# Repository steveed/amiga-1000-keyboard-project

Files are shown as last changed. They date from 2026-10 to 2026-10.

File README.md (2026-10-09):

# amiga-1000-keyboard-project
An open source replacement PCB for the Commodore Amiga 1000 keyboard.

Rendered top view of the board

Rendered angled view of the board

The switch plate, generated from the PCB (1.2 mm FR4, version 1):

Rendered switch plate

Renders are regenerated by GitHub Actions whenever the board or plate changes.

## Project Goals
1. Provide a drop-in replacement keyboard PCB for original Amiga 1000 machines.

## Controller
The board takes the original Amiga 1000 keyboard controller (a mask-ROM 6500/1). A 6570 from an
A500/A2000/A3000 keyboard also works if KCLK and KDAT are swapped: solder the cable's white and green
wires into each other's pads on J1. With the original controller: white = KCLK (PA0, pin 38),
green = KDAT (PA1, pin 37), red = +5V, black = GND.

## Building
Everything runs in Docker through `make` (KiCad 10 and a small Python image):

- `make print` - 1:1 print sheets in `build/print/` (one 11x17 sheet, or two Letter sheets to tape together).
  Print at 100% / Actual size and check the 100 mm bar.
- `make drc` - refill the pours and fail on any DRC error or schematic/board mismatch.
- `make bom` - regenerate `pcb/bom.csv` from the schematic's Part fields.
- `make fab` - gerbers and drill files, zipped in `build/fab/`.
- `make plate` - the switch plate (DXF and a gerber zip for FR4) in `build/plate/`, generated from the PCB.
- `make case` - the printable case (four STLs and a preview) in `build/case/`, from `case/a1000_case.scad`. See [case/README.md](case/README.md).
- `make rev2-sch`, `make rev2-pcb`, `make rev2-route`, `make rev2-drc` - the rev 2 board (ATmega32U4, surface mount, Cherry MX). See [pcb/rev_2/README.md](pcb/rev_2/README.md).
- `make render` - the README renders in `build/render/`.
- `make release` - all of the above, collected in `build/release/`.

Pushing a `v*` tag runs `make release` on GitHub and publishes the files as a GitHub release.

## Reference Material
- [docs/amiga-a1000-schematics-all.pdf](docs/amiga-a1000-schematics-all.pdf) - Amiga 1000 schematics

## Credits
Future revisions are expected to reuse parts of Henryk Richter's [A500KB](https://github.com/HenrykRichter/A500KB) mechanical keyboard. This project uses the same license so that work can be incorporated.

## License
The PCB, its design files and all support code are licensed under [Creative Commons Attribution-NonCommercial-ShareAlike 4.0 International (CC BY-NC-SA 4.0)](https://creativecommons.org/licenses/by-nc-sa/4.0/). See [LICENSE.txt](LICENSE.txt) for the full text.

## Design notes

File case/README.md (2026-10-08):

# Case

A printable case for the PCB and switch plate, shaped after the original Amiga 1000 keyboard.
Everything is generated from [`a1000_case.scad`](a1000_case.scad); `make case` writes the four
printable STLs and an assembly preview to `build/case/`.

Coordinates are the PCB's, as in [`docs/measurements.md`](../docs/measurements.md): x from the
PCB's left edge, y up from its front edge. z = 0 is the parting line between the two shells.

## Where the shape comes from

No original case was measured. The outside is taken from a 1:8 scale model of the keyboard (a 3MF,
"Keyboard PRINTABLE v8"; not kept in the repo). Its keycaps were fitted to
`docs/switch-positions.csv`: 66 single-width caps match at a scale of 7.99 with 0.27 mm RMS error,
so the model is accurate to well under a millimetre in plan. At full size:

- Case 405.7 x 157.9 x 23.6 mm, 25.85 mm on its feet. It overhangs the PCB by 8.0 mm at the left,
  8.45 at the right, 8.15 at the front and 4.8 behind the controller tab.
- Flat top, no wedge. The front and back edges are rounded (about r 5.9). The ends are square.
- A groove round the middle at the parting line (the model steps it; here it is one 1.6 x 1.2 mm groove).
- One stepped opening for the main block and the top row, and one for the keypad. Every keycap
  centre has at least 9.69 mm clear to the edge, so a full 19.05 mm cap envelope fits.
- The model's key wells have a floor at z = 0.8, read here as the plate top.
- A sloped label recess behind the keys (x 31.5-282.1, y 125.9-143.4), its floor rising from
  z 8.34 at the front to 10.27 at the back.
- A 15.5 mm badge recess at the rear right, 0.5 mm deep, where the original has the Amiga logo.
- A 0.3 mm label recess underneath, and four 19 mm square feet, 2.25 mm tall.

## From photos of an original case

Photos of an original top and bottom case (not kept in the repo), scaled from a steel rule in
the frame. Positions are good to a few millimetres.

- Overall length agrees with the model: about 406 mm.
- The bottom case has bosses at all four case-screw positions: the PCB's three 7.5 mm holes and
  the plate tab. The top case has matching bosses, so four screws, as modelled here.
- The keyboard cable is a coiled telephone handset cable. It plugs into a 4P4C jack that sits
  in a notch in the bottom case's back wall at about x 83-97, in a moulded pocket. That is left
  of J1 (x 123), which is wired to the jack.
- Rear corners: spring-loaded fold-out legs. Each is a hinged leg with a wire spring, lying
  along the back wall when folded, from the end wall to about 55 mm in. Not modelled yet;
  the model's two rear feet sit about where they fold.
- The top case has small ribs or hooks along the inside of its front wall. Not modelled.
- The plate carries an aluminium channel over the controller strip.

## Inside (designed here, not from the original)

- The bottom shell has a tongue that locates the top shell's walls.
- Four M3 screws from underneath, at the PCB's three 7.5 mm case holes and the plate tab's hole.
  A boss under the PCB (or under the tab) carries a 7 mm spigot up through the PCB and plate. A
  column in the top shell lands on the plate, with a heat-set insert. Tightening the screws clamps
  the plate and PCB between the shells.
- A skirt round each key opening runs down to 0.3 mm above the plate.
- A 4P4C jack pocket in the bottom shell at x 90, where the original's jack is: a plug opening in
  the back wall, and ribs on the floor that hold the jack body. It has to fit between the back
  wall and the PCB's step at y 134.9, so the jack can be at most about 10.4 mm deep (the render warns past that).

## Assumed, needs checking

- **Plate to PCB spacing** (`plate_to_pcb`, 5.0 mm). Not measured. It sets the PCB height and
  so the room under it (3.5 mm to the floor at 5.0, for the leads and the three resistors on the
  solder side).
- **Plate height** (`plate_top_z`, 0.8). From the model's well floor. It decides how far the
  keycaps stand proud of the top.
- **Jack size** (`jack_body`, `jack_plug`). Typical 4P4C values; measure the jack you fit.
- **Tall parts under the label recess.** Y1 is laid flat on the original (about 5 mm tall), so it
  fits; standing up (13.5 mm) it would not, with 12.3 mm above the PCB there. C8 and the socketed
  controller fit too.

## Printing

| part | size (mm) | orientation |
|---|---|---|
| top_left | 220 x 158 x 12 | face down |
| top_right | 198 x 158 x 12 | face down |
| bottom_left | 193 x 158 x 17 | feet down |
| bottom_right | 227 x 158 x 17 | feet down |

The STLs come out in their print orientation. Each shell splits into two on a 45 degree scarf
(glue it), and the two splits are staggered so the shells bridge each other's joint. The rounded
edges stop at 45 degrees and finish with a small chamfer at the bed (`print_safe`), so nothing
needs supports. The exception is the label recess, which prints as a ~17 mm bridge.

## Hardware

- 4 M3 x 14 screws, pan or button head (12-16 works: the head sits 3 mm up in a counterbore and the insert runs 5 mm up the column).
- 4 M3 heat-set inserts, 4 mm hole.

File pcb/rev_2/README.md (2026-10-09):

# Rev 2

A surface-mount version of the board that the fab can assemble from stocked parts, for Cherry MX
switches; only the keyswitches and the Caps Lock LED (which sits inside its switch) are fitted by hand. Rev 1, the
through-hole recreation of the original that takes the original 6500/1 controller, stays in `pcb/`.

The outline, mounting holes and switch positions match rev 1, so the case fits both boards; rev 2
needs its own MX plate.

## Schematic

`amiga-1000-keyboard-rev2.kicad_sch` is generated by `tools/gen_rev2_sch.py`: edit the script and
run `make rev2-sch`, which regenerates it and runs ERC. The switches keep rev 1's references and
key names.

- **Controller:** ATmega32U4 at 16 MHz, in place of the mask-ROM 6500/1. Its firmware will be
  ported from Henryk Richter's [A500KB](https://github.com/HenrykRichter/A500KB) (AVR, same licence).
  Flashing:
  - first time: the 32U4 ships with Microchip's USB (DFU) bootloader, and a chip with empty flash
    runs straight into it, so it can be flashed over USB as it comes (to confirm on the first board);
  - updates: the firmware jumps to the bootloader on a key combination, then flash over USB;
  - recovery, if the firmware can't get there: short JP2 (BOOT) while shorting JP1 (RESET), then
    flash over USB; or use the 6-pin ISP header (J3, not fitted; a pogo adapter or a soldered header
    and any AVR programmer), which works even without the bootloader.
- **Amiga and USB both live:** the Amiga cable (J1, same pin order as rev 1's J1: GND, +5V, KCLK,
  KDAT) and a USB-C socket (J2) are on every board. The keyboard works on either, or both at once. Plugging
  both in is safe: the TPS2116 keeps the two 5 V supplies apart (no back-feeding either way), and the
  firmware only pulls KCLK and KDAT while the Amiga's 5 V is present. With both connected, the
  Amiga's and the PC's grounds are joined through the keyboard, as with any USB device.
- **Power:** a TPS2116 power mux. The Amiga's 5 V has priority; USB takes over when it's absent
  (below about 4.3 V), with no diode drop. Its status output (AMIGA_PWR, on PE6) tells the firmware
  whether the Amiga is powered, so it never pulls KCLK or KDAT on a switched-off machine.
- **USB:** USBLC6-2SC6 ESD protection, a 500 mA resettable fuse, 22 R series resistors and the
  5.1 k CC resistors that make it a USB-C device.
- **Matrix:** 8 rows x 12 columns, one diode per key, so any combination of keys reads correctly.
  Each physical row's first 12 keys take electrical rows 0-5; the rest fill rows 6 and 7. SW55
  and SW58 (the international keys) get their own positions; SW92 (short ISO left shift) is fitted
  instead of SW87 and shares its position.

## Switches

Rev 2 takes Cherry MX (and compatible) switches; rev 1 is the Mitsumi replacement. The footprints
come from `tools/gen_mx_fp.py`, in the standard orientation (pins north, LED holes south), with
PCB-mount pegs. Keycap widths come from rev 1's switch spacing. Keys of 2U and wider have PCB-mount
stabiliser holes; the space bar (7.5U) uses a 7U stabiliser (114.3 mm). Return follows Henryk
Richter's US Return for the A500KB: the switch at the key's stem, the centre of the column the cap
has on both rows, with a vertical 2U stabiliser. It suits the US inverted L and the international
Return alike.

SW87 (US 2.5U left Shift) and SW92 (ISO 1.5U short Shift) are alternatives under the same keycaps.
Their facing pegs would be 0.54 mm apart, so SW87 has no west peg and SW92's east peg is a slot
either switch's peg fits.

The Caps Lock LED (D92) is a 3 mm LED through the Caps Lock switch, fitted by hand with it.

## Board

`amiga-1000-keyboard-rev2.kicad_pcb` is generated, then routed:

- `make rev2-pcb` (`tools/gen_rev2_pcb.py`) builds it from rev 1's board and the rev 2 schematic:
  rev 1's outline, stack-up, design rules and GND pours, with rev 2's footprints linked to the
  schematic and placed. The file comes out the same on every run (footprints in reference order,
  UUIDs derived from references), which matters because the router's result depends on file order.
- `make rev2-route` routes it with [KiCadRoutingTools](https://github.com/drandyhaas/KiCadRoutingTools)
  (`tools/route_rev2.py`), following the passes in `tools/rev2_route.json`, then removes the vias
  and tracks left dangling (`tools/rev2_cleanup.py`).
- `make rev2-drc` checks it, schematic parity included.

Placement and routing notes:

- Switches sit at rev 1's key centres; Return at its stem.
- Each key's diode is on the back, between its row and the next, at the first spot that clears every
  pad and hole by 0.5 mm.
- The controller, USB-C and power parts are on the strip behind the keys. USB-C opens to the left out
  of the step at the left end of the strip, so a right-angle USB-C cable (a common part for Amiga
  mods) can turn and leave through the jack notch, which keeps the original case usable; the Amiga
  header (J1) sits on the board's back edge behind the jack.
- U1 sits on the right of the strip, where rev 1's controller was, so the matrix lines run along the
  strip instead of converging mid-board. It's turned so its row pins face the keys, and fanned out: every pin but the crystal and USB data
  pins has a short track to its own via, on two staggered rings. About 20 matrix lines converge on
  this 0.8 mm-pitch chip on two layers, and the router reaches a ring of vias far more easily than
  the pads. A few decoupling caps sit on the back, under it (the diodes already make it a two-sided
  assembly).
- The TPS2116's VIN2 and GND pins have pre-routed escapes too: they're 0.5 mm-pitch pins the router
  kept falling just short of.
- Routing order matters (see `tools/rev2_route.json`): ROW5, the longest run into U1, goes first;
  then VBUS; then the USB and power nets at 0.2 mm clearance (their 0.5 mm-pitch pins are too tight
  for 0.25); then the other rows; then everything else at 0.25 mm, which keeps tracks clear of the
  MX holes; then GND.
- `amiga-1000-keyboard-rev2.kicad_dru` allows the overlaps that are meant (the left Shift
  alternatives, the Caps Lock LED inside its switch, the plate screws between switches) and one
  thermal spoke on GND pads.

### KiCadRoutingTools

`make rev2-route` runs in a `krt:local` image built from a KiCadRoutingTools checkout, with its Rust
router built inside it:

```
FROM python:3.12-slim
WORKDIR /krt
COPY requirements.txt .
RUN pip install --no-cache-dir -r requirements.txt
COPY . .
RUN rm -f rust_router/*.so && python3 build_router.py
```

Build it from the checkout (`docker build -f <that Dockerfile> -t krt:local .`). Routing takes about
five minutes.

## Ordering from JLCPCB

Every push to `main` that touches rev 2 runs the "Rev 2 for JLCPCB" GitHub workflow: DRC and
schematic parity, then gerbers, BOM and placement, uploaded as the artifact
`amiga-1000-keyboard-rev2-jlcpcb`. Locally, `make rev2-fab rev2-jlc` writes the same files to
`build/rev2-fab/` and `build/rev2-jlc/`.

- **PCB:** upload `amiga-1000-keyboard-rev2-gerbers.zip`. Two layers, 1.6 mm.
- **Assembly:** both sides (the key diodes and two of U1's decoupling caps are on the back). Upload
  `bom-jlc.csv` and `cpl-jlc.csv`, then check the placement preview: the rotation corrections in
  `tools/jlc_export.py` cover the ICs, but check every part's orientation, especially the diodes and
  U1-U3, before ordering.
- **Parts:** 123 parts in 18 lines, LCSC numbers checked against JLCPCB's parts library. Six are
  Extended parts with a setup fee each (U1, U2, U3, J1, J2 and F1); the rest, all the passives and
  the crystal included, are Basic. The crystal is a 9 pF-load part, so its load caps are 12 pF.
- **Plate:** `amiga-1000-keyboard-rev2-plate-us-gerbers.zip` or `...-plate-iso-gerbers.zip`, as a
  second PCB order: 1.6 mm FR4, no copper needed (the gerbers carry only the outline and mask).
  The DXFs are there for laser-cut metal. See "MX plates" below.
- **Fitted by hand:** the switches and stabilisers, the Caps Lock LED (D92), and the ISP header (J3)
  if you want it. The 1 nF caps C13-C15 are left off, as on the original.

## MX plates

`make rev2-plate` (`tools/make_plate.py`) generates the plate from the board, in two variants, as
Henryk does for the A500KB: the US left Shift's stabiliser would land in the ISO short Shift's switch
hole, so one plate can't take both. The board takes either.

- **US:** the 2.5U left Shift (SW87); no SW92 (ISO short Shift), SW58 (the < > key) or SW55 (the
  international key under Return). 89 switches.
- **ISO:** SW92, SW58 and SW55; no SW87. 91 switches.

Both have 14 mm Cherry MX switch cut-outs, the Cherry stabiliser cut-outs from Henryk's
MX_Mitsumi_Hybrid plate footprints (2U keys, the left Shift, the 7U space bar stabiliser and a
vertical one for Return), rev 1's outline, tab and case holes, and the plate screw holes except H8,
which sits under keypad Enter's stabiliser. 1.6 mm FR4: MX switches clip best into 1.5 mm, but 1.6 mm
is JLCPCB's FR4 thickness nearest to it and the usual choice for FR4 keyboard plates.

## Pins

| Function | Pins |
|---|---|
| Rows 0-7 | PF0, PF1, PF4, PF5, PF6, PF7, PC6, PD7 |
| Columns 0-11 | PB0-PB6, PD0, PD1, PD4, PD5, PD6 |
| KCLK, KDAT | PD2, PD3 (INT2/INT3, and the UART for debug output) |
| Caps Lock LED | PB7 (PWM) |
| Amiga powered | PE6 |
| Bootloader (HWB) | PE2 |
| Spare | PC7, on a test pad |

PF4-PF7 are the JTAG pins: the firmware must turn JTAG off (MCUCR.JTD) before it uses them as rows.

## Still to do

- Firmware: port Henryk's A500KB firmware to the 32U4 and this matrix.
- Build and test the first board, including the factory USB bootloader on a blank chip.

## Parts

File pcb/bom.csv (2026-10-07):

Refs | Qty | Part | Footprint | DNP
C1-C3 | 3 | 1nF 50V ceramic disc, 5 mm | Capacitor_THT:C_Disc_D5.0mm_W2.5mm_P5.00mm | DNP
C4,C7 | 2 | 100nF 50V ceramic disc, 5 mm | Capacitor_THT:C_Disc_D5.0mm_W2.5mm_P5.00mm
C5 | 1 | 1uF 25V tantalum, 2.5 mm | Capacitor_THT:CP_Radial_Tantal_D4.5mm_P2.50mm
C6 | 1 | 10nF 50V ceramic disc, 5 mm | Capacitor_THT:C_Disc_D5.0mm_W2.5mm_P5.00mm
C8 | 1 | 47uF 16V electrolytic, 5 mm dia, 2 mm | Capacitor_THT:CP_Radial_D5.0mm_P2.00mm
C9 | 1 | 22pF 50V C0G ceramic disc, 5 mm | Capacitor_THT:C_Disc_D5.0mm_W2.5mm_P5.00mm
D1 | 1 | 1N4148 small-signal diode, DO-35 (original: unmarked glass, yellow cathode band, likely a 1S1588) | Diode_THT:D_DO-35_SOD27_P7.62mm_Horizontal
D2 | 1 | LED built into the Caps Lock switch (no separate part) | amiga1000:Mitsumi_A1000_CapsLock_LED
FB1-FB3 | 3 | Axial ferrite bead, e.g. Fair-Rite 2743001112 | Inductor_THT:L_Axial_L9.5mm_D4.0mm_P12.70mm_Horizontal_Fastron_SMCC
J1 | 1 | Original 4-wire cable soldered in (or a 1x4 2.54 mm header) | Connector_PinHeader_2.54mm:PinHeader_1x04_P2.54mm_Vertical
Q1 | 1 | 2SC2021 (Rohm SPT, original) or 2SC1815/KSC1815 TO-92; any small NPN with E-C-B pinout | amiga1000:TO-92_Inline_Wide_ECB
R1 | 1 | 150R 1/4W axial | Resistor_THT:R_Axial_DIN0207_L6.3mm_D2.5mm_P10.16mm_Horizontal
R2 | 1 | 510K 1/4W axial | Resistor_THT:R_Axial_DIN0207_L6.3mm_D2.5mm_P10.16mm_Horizontal
R3 | 1 | 560K 1/4W axial | Resistor_THT:R_Axial_DIN0207_L6.3mm_D2.5mm_P10.16mm_Horizontal
SW1-SW54,SW56,SW57,SW59-SW91 | 89 | Mitsumi standard mechanical Type 2 (KCT) keyswitch, salvaged | amiga1000:Mitsumi_A1000_Switch
SW55 | 1 | Dummy Mitsumi housing (one leg, no spring) supporting the Return keycap on US layouts; a real switch on international layouts | amiga1000:Mitsumi_A1000_Switch
SW58,SW92 | 2 | Mitsumi standard mechanical Type 2 (KCT) keyswitch, salvaged | amiga1000:Mitsumi_A1000_Switch | DNP
U1 | 1 | Commodore 6500/1 keyboard controller, salvaged from an A1000 keyboard (or a 6570 with white/green swapped) | Package_DIP:DIP-40_W15.24mm
U2 | 1 | NE556N dual timer, DIP-14 | Package_DIP:DIP-14_W7.62mm
Y1 | 1 | 3.000 MHz crystal, HC-49/U | Crystal:Crystal_HC49-U_Vertical

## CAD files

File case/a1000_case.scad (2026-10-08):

// a1000_case.scad
//
// Printable case for the Amiga 1000 keyboard PCB and switch plate, shaped after the original.
//
// The outside (outline, edge profile, parting groove, key openings, label and badge recesses,
// feet) is measured from a 1:8 scale model of the original keyboard, fitted to this board's
// switch positions (66 keycaps matched to 0.27 mm RMS at a scale of 7.99).  The inside (how the
// plate and PCB are held, screws, the joints for printing) is designed here.  See README.md
// for the numbers and what is still assumed.
//
// Coordinates are the PCB's, as in docs/measurements.md: x from the PCB's left edge, y up from
// its front edge (+y is away from the typist), component side up.  z = 0 is the parting line
// between the top and bottom shells, in the middle of the groove that runs round the case.
//
// Four printed parts, each fits a 256 x 256 mm bed:
//   top_left / top_right        top shell, printed face down, joined on a 45 degree scarf at top_split_x
//   bottom_left / bottom_right  bottom shell, printed feet down, joined the same way at bottom_split_x
// The two splits are staggered so each shell bridges the other's joint.
//
// Fixings: 4x M3 screws from underneath, through the bottom bosses, the PCB/plate case holes
// and into heat-set inserts in the top shell's columns.  They clamp the plate and PCB between
// the two shells, like the original's case screws.
//
// Render one part:  openscad -o top_left.stl -D 'part="top_left"' a1000_case.scad

part = "assembly"; // ["assembly","top","bottom","top_left","top_right","bottom_left","bottom_right"]
show = ["top", "bottom", "board"];  // what the assembly view includes
explode = 0;                        // lift the top shell this far in the assembly view

/* ---------------------------------------------------------------- parameters */

// Shell
wall          = 2.6;    // front, back and end walls.  The groove leaves wall - groove_d at the parting line.
top_skin      = 2.5;    // top shell thickness
floor_t       = 2.5;    // bottom shell thickness
label_skin    = 1.6;    // material left under the sloped label recess
print_safe    = true;   // stop the rounded edges at 45 degrees and finish with a chamfer, so both
                        // shells print without supports.  false = the full round.

// Board stack.  The model shows the plate at z = 0.8 (the floor of its key wells); the rest is assumed.
plate_top_z   = 0.8;    // plate top surface
plate_t       = 1.2;    // 1.2 mm FR4 plate (version 1); the original steel plate is 1.25
plate_to_pcb  = 5.0;    // plate top -> PCB top.  NOT MEASURED: depends on the Mitsumi switches.
pcb_t         = 1.6;

// Key wells: a skirt round each opening, down to just above the plate, as in the original
skirt_t       = 1.2;
skirt_gap     = 0.3;    // skirt bottom -> plate top

// Shell joint: a tongue on the bottom shell that drops inside the top shell's walls
tongue_t      = 1.2;
tongue_h      = 2.5;
tongue_clear  = 0.2;

// Screws and bosses
boss_d        = 11;     // bottom boss under the PCB / plate tab
spigot_d      = 7.0;    // passes up through the 7.5 mm case holes in the PCB and plate
squeeze       = 0.2;    // spigot stops this far below the plate top, so the screws clamp the stack
column_d      = 10;     // top shell column that lands on the plate
insert_d      = 4.0;    // M3 heat-set insert (2.6 to self-tap instead)
insert_depth  = 5.0;
screw_clear_d = 3.4;
cbore_d       = 6.5;    // M3 pan/button head
cbore_depth   = 3.0;

// Printing splits: 45 degree scarf joints, glued
top_split_x    = 200;
bottom_split_x = 185;

// 4P4C (handset) jack in the back wall: the original's coiled cable plugs in here.  The notch
// in the original bottom case is at about x 83-97 (scaled from a photo).  The jack sits on the
// floor against the back wall, held between ribs; J1 is wired to it.  Jack sizes are typical
// values, NOT MEASURED: check them against the jack you use.
jack_x        = 90;     // centre of the jack
jack_body     = [11.5, 10.0, 11.0];   // jack body width (x), depth (y), height (z)
jack_plug     = [8.4, 7.2];           // plug opening in the back wall, width x height (the notch runs on up to the parting line)
rib_t         = 1.6;    // ribs that hold the jack
rib_clear     = 0.2;

feet          = "printed";  // ["printed","none"]: the model shows four square feet

$fn = 48;

/* ------------------------------------------------ geometry from the scale model */

// Outside of the case.  The front and back edges are rounded, the ends are square.
CX0 = -8.0;   CX1 = 397.7;
CY0 = -8.15;  CY1 = 149.75;
CZ  = 11.8;            // top at +CZ, bottom at -CZ
edge_r = 5.9;          // front and back edge radius

// Parting groove round the middle (the model steps it; one 1.6 x 1.2 groove is close enough)
groove_h = 1.6;
groove_d = 1.2;

// Key openings.  One stepped opening for the main block and top row, one for the keypad.
main_open = [[2.92, 120.13], [25.1, 120.13], [25.1, 101.1], [31.47, 101.1], [31.47, 120.13],
             [153.6, 120.13], [153.6, 101.1], [159.97, 101.1], [159.97, 120.13],
             [282.1, 120.13], [282.1, 101.1], [288.47, 101.1], [288.47, 120.13],
             [310.65, 120.13], [310.65, 43.99], [320.17, 43.99], [320.17, 21.8], [310.65, 21.8],
             [310.65, 2.77], [288.47, 2.77], [288.47, 21.8], [267.82, 21.8], [267.82, 2.77],
             [26.71, 2.77], [26.71, 21.8], [2.92, 21.8]];
pad_open  = [[326.54, 2.77], [386.8, 2.77], [386.8, 101.1], [326.54, 101.1]];

// Label recess behind the keys: its floor slopes up towards the back
LBL = [31.47, 125.9, 282.1, 143.35];   // x0, y0, x1, y1
lbl_z0 = 8.34;   // floor height at the front edge
lbl_z1 = 10.27;  // and at the back edge

// Badge recess, rear right (the original carries the Amiga logo here)
badge_c = [379.05, 131.05];
badge_w = 15.5;
badge_r = 1.5;
badge_depth = 0.5;

// Label recess under the case
BLBL = [79.94, 52.81, 149.89, 104.27];
blbl_depth = 0.3;

// Feet: 19 mm square, 2.25 mm tall
foot_w = 19;
foot_h = 2.25;
foot_c = [[36.47, 7.84], [353.25, 7.84], [36.47, 108.77], [353.25, 108.77]];

/* ------------------------------------------------ geometry from the PCB (docs/measurements.md) */

// PCB outline: the back edge steps, the front edge is straight
pcb_outline = [[0, 0], [389.25, 0], [389.25, 119.60], [342.95, 119.60], [342.95, 144.99],
               [103.55, 144.99], [103.55, 134.90], [71.10, 134.90], [71.10, 121.36], [0, 121.36]];
// Switch plate: 2 mm wider than the PCB each side, with a tab on the back edge
plate_outline = [[-2.0, 0.46], [391.25, 0.46], [391.25, 121.36], [66.8, 121.36], [66.8, 146.36],
                 [48.8, 146.36], [48.8, 121.36], [-2.0, 121.36]];

// Case screws: the PCB's three 7.5 mm case holes (through the plate too) and the plate tab's hole
pcb_screws = [[16.7, 15.3], [318.14, 15.23], [375.64, 110.28]];
tab_screw  = [57.8, 133.86];
tab_x      = [48.8, 66.8];

// The tallest parts on the controller strip: [ref, x, y, footprint w, d, height above the PCB]
// Y1 lies flat, its can towards the front (the Crystal_HC49-U_Horizontal footprint)
tall_parts = [["Y1 crystal (HC-49/U, laid flat)", 247.25, 129.65, 10.9, 13.0, 5.0],
              ["C8 47 uF electrolytic",          174.6, 136.85, 5.0, 5.0, 11.0],
              ["U1 6500/1 in a socket",          319.6, 138.15, 52.0, 15.5, 8.5]];

/* ---------------------------------------------------------------- derived */

plate_bot_z = plate_top_z - plate_t;
pcb_top_z   = plate_top_z - plate_to_pcb;
pcb_bot_z   = pcb_top_z - pcb_t;
ceil_z      = CZ - top_skin;           // inside of the top shell
floor_z     = -CZ + floor_t;           // inside of the bottom shell
IX0 = CX0 + wall; IX1 = CX1 - wall;    // cavity
IY0 = CY0 + wall; IY1 = CY1 - wall;

function lbl_floor(y) = lbl_z0 + (y - LBL[1]) * (lbl_z1 - lbl_z0) / (LBL[3] - LBL[1]);
function in_lbl(x, y, m = 0) = x > LBL[0] - m && x < LBL[2] + m && y > LBL[1] - m && y < LBL[3] + m;
// inside of the top shell at (x, y): lower under the label recess
function ceiling_at(x, y) = in_lbl(x, y, label_skin) ? lbl_floor(min(max(y, LBL[1]), LBL[3])) - label_skin : ceil_z;

echo(str("case: ", CX1 - CX0, " x ", CY1 - CY0, " x ", 2 * CZ, " mm (", 2 * CZ + (feet == "printed" ? foot_h : 0), " on its feet)"));
echo(str("plate top ", plate_top_z, ", PCB top ", pcb_top_z, ", under the PCB ", pcb_bot_z - floor_z, " mm to the floor"));
if (IY1 - jack_body[1] - rib_t < 134.90) echo(str("WARNING: the jack pocket reaches y ", IY1 - jack_body[1] - rib_t,
                                                  ", past the PCB's back edge at 134.90 there"));
for (p = tall_parts) {
    room = ceiling_at(p[1], p[2]) - pcb_top_z;
    echo(str(room < p[5] ? "WARNING: " : "", p[0], ": ", room, " mm above the PCB, part is ", p[5]));
}
echo(str("top halves ", top_split_x + CZ - CX0, " / ", CX1 - top_split_x,
         "   bottom halves ", bottom_split_x - CX0, " / ", CX1 - bottom_split_x + CZ));
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

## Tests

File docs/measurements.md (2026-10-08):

# A1000 keyboard PCB measurements

Taken from a reproduction PCB (outline and markings copied from the original, `KCT-A89YC 56-7155B`).
Reference photos are kept out of the repo.

## Confirmed
- Key pitch: 19.05 mm.
- Cable: four wires (black, red, green, white) soldered directly to pads at the left end of the
  component strip, held by a fabric tie through the board. Each passes through a through-hole ferrite.
  The other end goes to a 4P4C modular jack. Black = GND, red = +5V (per owner). By meter, white goes
  to the 6500's pin 38 (PA0) and green to pin 37 (PA1). At the cord's computer end, white is on pin 2
  (KCLK on the A1000 jack). So white = KCLK = PA0 and green = KDAT = PA1, matching the drawing.
- Computer side (A1000 main schematic, J9 KBD): 1 +5V, 2 KCLK, 3 KDAT, 4 GND.
- Three axial resistors are soldered on the solder side next to the X3 cable pads, one lead of each to a
  common pad and the other leads to three separate pads. They aren't on drawing 327063. Value unclear
  from the photo (bands look like red/brown-black-red, so roughly 1K-2K).

## Parts read from an assembled board
- Switches: Mitsumi standard mechanical Type 2 ("KCT" type, matching the `KCT-A89YC` PCB marking).
  13.5 mm square base. Seen from the top, the two pins sit 2.0 mm in from the right edge of the base
  (caliper: pin to far edge ~11.5 mm), so the body and keycap centre is 4.75 mm left of the pin midpoint.
  Cross-check: with that offset the rotated RETURN switch's body centre lands on the home row.
- The short ISO left-shift position (SW92) is wired in parallel with L SHIFT (SW87), checked with a meter.
- Caps Lock LED (inside the Caps Lock switch): leads 2.7 mm apart; the upper lead (towards the F-keys) is the
  anode, checked with a meter.
- Crystal: 3.000 MHz, HC-49/U can about 10 x 13 mm, leads 5 mm apart (marked "3.000 UNI 85 E").
  It is laid flat on the board, leads at the back and the can towards the keys (Crystal_HC49-U_Horizontal),
  which the case needs: there isn't room for it standing under the label recess.
- Controller: 40-pin DIP marked "R10L2-11 / MEXICO A / 0106 / 8535" (Commodore logo).
- Timer: TI NE556N (confirms the 556; the board silkscreen's "NE566N" is a typo).
- Crystal load cap 22 pF; 104 (0.1 uF) ceramic decoupling next to the controller.
- Switches mount in a black steel plate held with small screws.

## From the flatbed scans (200 dpi, calibrated to the 19.05 mm key pitch)
Coordinates are mm, x from the left edge and y up from the front edge, component side up.
Hole and switch centres come from the scan; edges are taken from the caliper.
- Overall length: 389.25 mm. Checked by caliper from the 7.5 mm case holes to the end edges: left edge to the
  (16.7, 15.3) hole's near edge 13.01 mm, right edge to the (375.7, 110.2) hole's near edge 9.95 mm. With the
  scan's hole spacing that gives 389.4 mm; the right end matches the board to 0.01 mm and the left end is 0.16 mm
  short, which is within the scan's accuracy, so the outline stays at 389.25. A steel ruler read ~388.4 mm, but
  the edges were hard to read against the shiny ruler, so the caliper figure wins.
- Outline, by caliper, looking at the top of the keyboard. The back edge steps; the front edge is straight.
  | Section (left to right) | Width | Depth |
  |---|---|---|
  | Left end | 71.10 | 121.36 |
  | First step | 32.45 | 134.90 |
  | Controller tab | 239.40 (remainder, from scan length) | 144.99 |
  | Keypad end | 46.30 | 119.60 |
  The scan agrees to within ~1 mm on the widths. Its depths read 0.25-0.5 mm high, consistent with edge
  blur at 200 dpi, so use the caliper numbers for the outline and the scan for hole and switch centres.
- 91 switches, matching the schematic. Two pins per switch, 9.04 mm apart, one above the other.
  Centres are in `switch-positions.csv`. Rows are on a 19.05 mm pitch. Keys within a row are 19.05 mm
  apart, but the rows aren't all offset by quarter units, so use the measured positions.
- Round holes (centres from the scan; diameters confirmed by caliper):
  - 7.5 mm, clearance for the case screws: (16.7, 15.3), (318.2, 15.2), (375.7, 110.2)
  - 3.8 mm, screws to the plate: (24.4, 15.3), (25.1, 110.0), (108.7, 15.2), (113.6, 62.7), (209.0, 110.0), (213.5, 15.1),
    (294.6, 62.8), (349.1, 15.2), (361.4, 110.5)
- Rectangular cut-outs, ~6.5 x 10.4 mm: centres (89.3, 14.0) and (204.2, 14.0).

## Switch plate (caliper)
Steel, 1.25 mm thick. Coordinates as above (x from the PCB's left edge, y up from its front edge).
- Outline: 393.25 x 120.9 mm; 2 mm wider than the PCB on each side (x -2.0 to 391.25). The back edge is
  flush with the PCB's left-end back edge (y 121.36), so the front edge is at y 0.46.
- Tab: flat, 18 mm wide, 25 mm deep, on the back edge, its left edge 50.8 mm from the plate's left edge
  (x 48.8-66.8, y 121.36-146.36). 7.5 mm hole centred in it, at (57.8, 133.86). It sits past the PCB's back
  edge, where the PCB is only 121.36 mm deep.
- PCB screw holes: tapped, for screws with a ~2.48 mm thread (likely M2.5; pitch not measured). They line up
  with the PCB's nine 3.8 mm holes; the size difference suggests extruded bosses that sit in those holes.
- Case: through-holes for the case screws line up with the PCB's three 7.5 mm case holes, plus the 7.5 mm hole in the tab.
- Switch cut-outs: 14 x 14 mm.
- The front and back edges are folded into a C shape that holds the plate at a set height above the PCB
  (not measured).
- Stabilizer slots (wide keys other than the space bar): 3 x 15 mm, 2.6 mm from the switch cut-out, under both Shifts, Return (the large
  L-shaped key), Tab, Backspace, keypad 0 and keypad Enter.
- Space bar stabilizer cut-outs: 7.1 mm wide x 11 mm tall, ~115 mm apart centre to centre (caliper), so they sit
  over the PCB's 6.5 x 10.4 mm cut-outs (centres x 89.28 and 204.22, 114.94 mm apart), symmetric about the
  space bar key centre (x 146.81 = pins - 4.75). Use the PCB cut-out centres for the plate.
- SW55 (home row, left of Return) holds a dummy housing on US boards: one leg, no spring, supporting the
  Return keycap. SW41 (Return) body sits behind its pins, in the gap below DEL/HELP.

## Plate, version 1
1.2 mm FR4 (`make plate`), held in place by the switches: no folded edges, and 2.7 mm clearance holes in place
of the tapped M2.5 holes, so screws and spacers can be added later if needed. A steel plate like the original
would need the folded edges measured and the holes drawn at the 2.05 mm tap drill.

## To confirm
- Plate (steel only): folded edge dimensions, PCB screw pitch.
- Switch pin hole diameter: about 1.2 mm (rough caliper reading). Check by finding the largest drill bit that fits.
- Cable pad positions (likely the pads marked X3).

## Differences from drawing 327063 rev B
- Resistor values: the repro silkscreen gives R1 510K, R2 82K, R3 150 (LED); the drawing gives 510K and 560K
  for the reset timer. On the assembled board, the resistor beside the 556 reads green-blue-yellow (560K)
  and the one near the crystal reads green-brown-yellow (510K). So the fitted parts match the drawing and
  the "82K" silkscreen looks wrong. Colour bands read from a photo; a meter check would settle it.
- 47 uF 16 V electrolytic fitted, as on the drawing.
- The timer is silkscreened NE566N, but the part fitted is an NE556N.

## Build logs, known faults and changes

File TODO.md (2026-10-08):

# TODO

1. ~~**PCB measurements**~~ - done from photos, scans and calipers (`docs/measurements.md`).
   Overall length checked by caliper from the case holes (389.4 mm vs 389.25 drawn).
2. ~~**Layout/routing**~~ - placed to match the reproduction board and routed with KiCadRoutingTools.
3. **Print test fit** - `make print`, print at 100%, and test against the case, plate and keycaps.
4. ~~**Create plate from original**~~ - version 1 is a 1.2 mm FR4 plate generated from the PCB (`make plate`).
   A steel version needs the folded edges measured.
5. **Fab** - tag a release (`v*`) to build gerbers, then order boards.
6. **Custom case** - first pass shaped from a 1:8 model (`make case`, `case/README.md`).
   Still to measure: plate to PCB spacing, plate height under the keycaps and the jack size.

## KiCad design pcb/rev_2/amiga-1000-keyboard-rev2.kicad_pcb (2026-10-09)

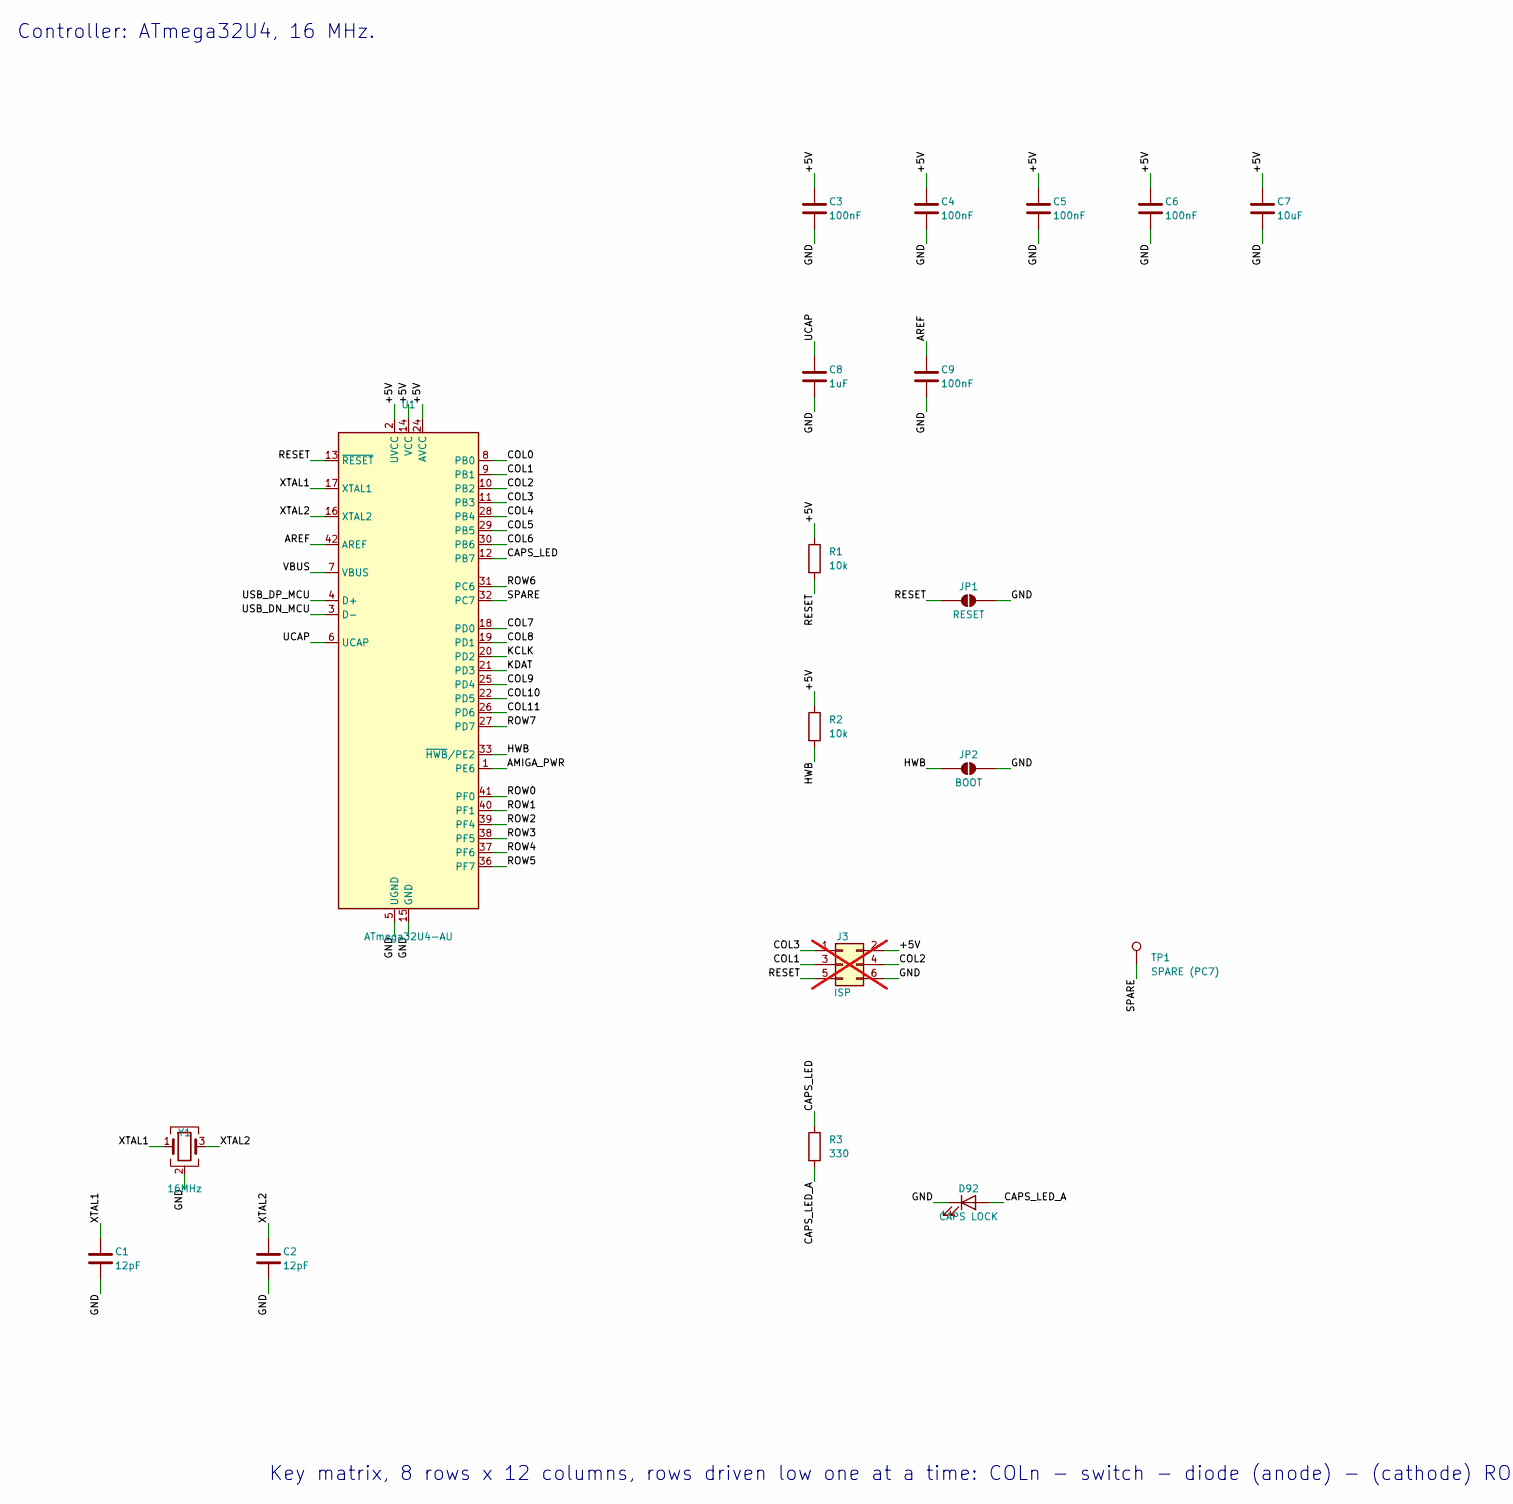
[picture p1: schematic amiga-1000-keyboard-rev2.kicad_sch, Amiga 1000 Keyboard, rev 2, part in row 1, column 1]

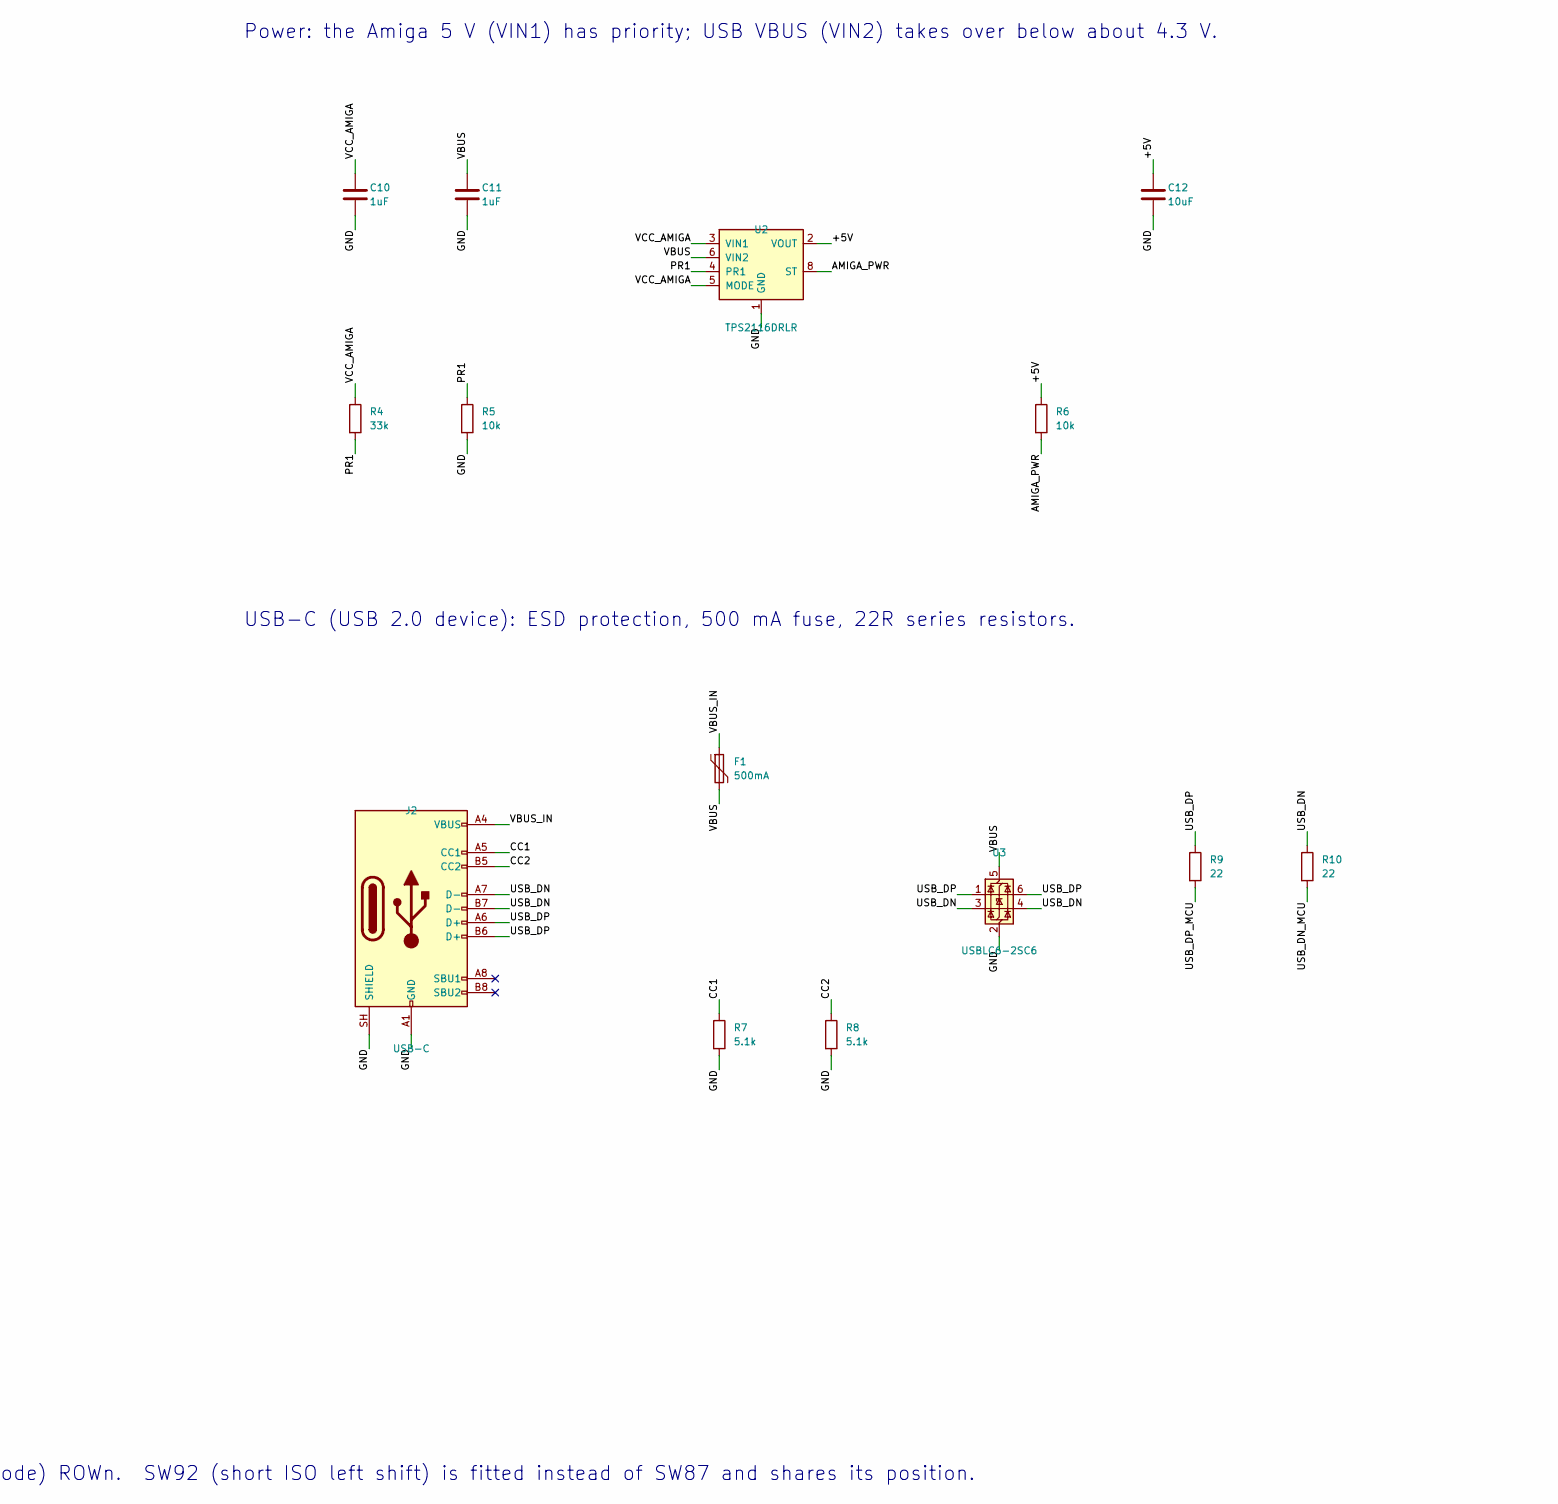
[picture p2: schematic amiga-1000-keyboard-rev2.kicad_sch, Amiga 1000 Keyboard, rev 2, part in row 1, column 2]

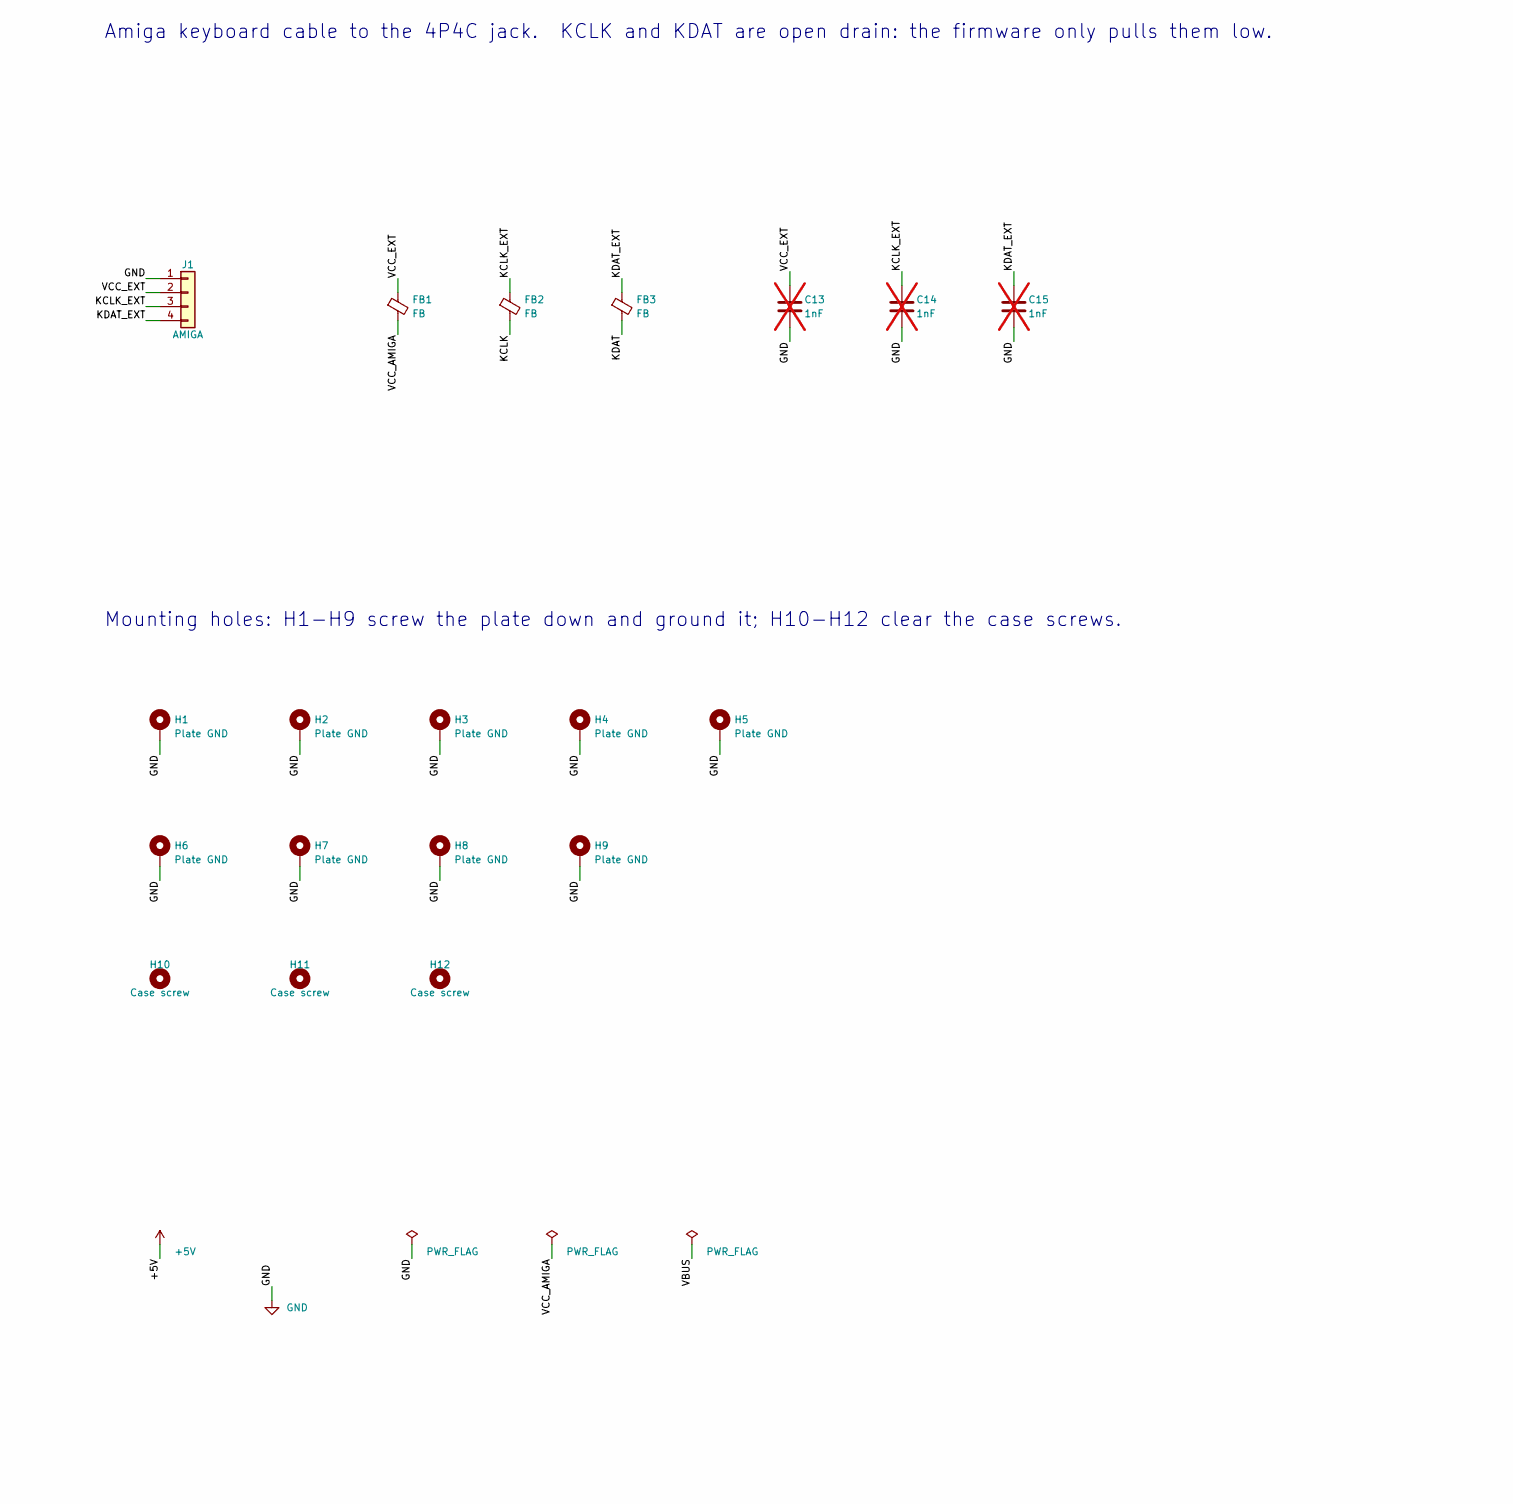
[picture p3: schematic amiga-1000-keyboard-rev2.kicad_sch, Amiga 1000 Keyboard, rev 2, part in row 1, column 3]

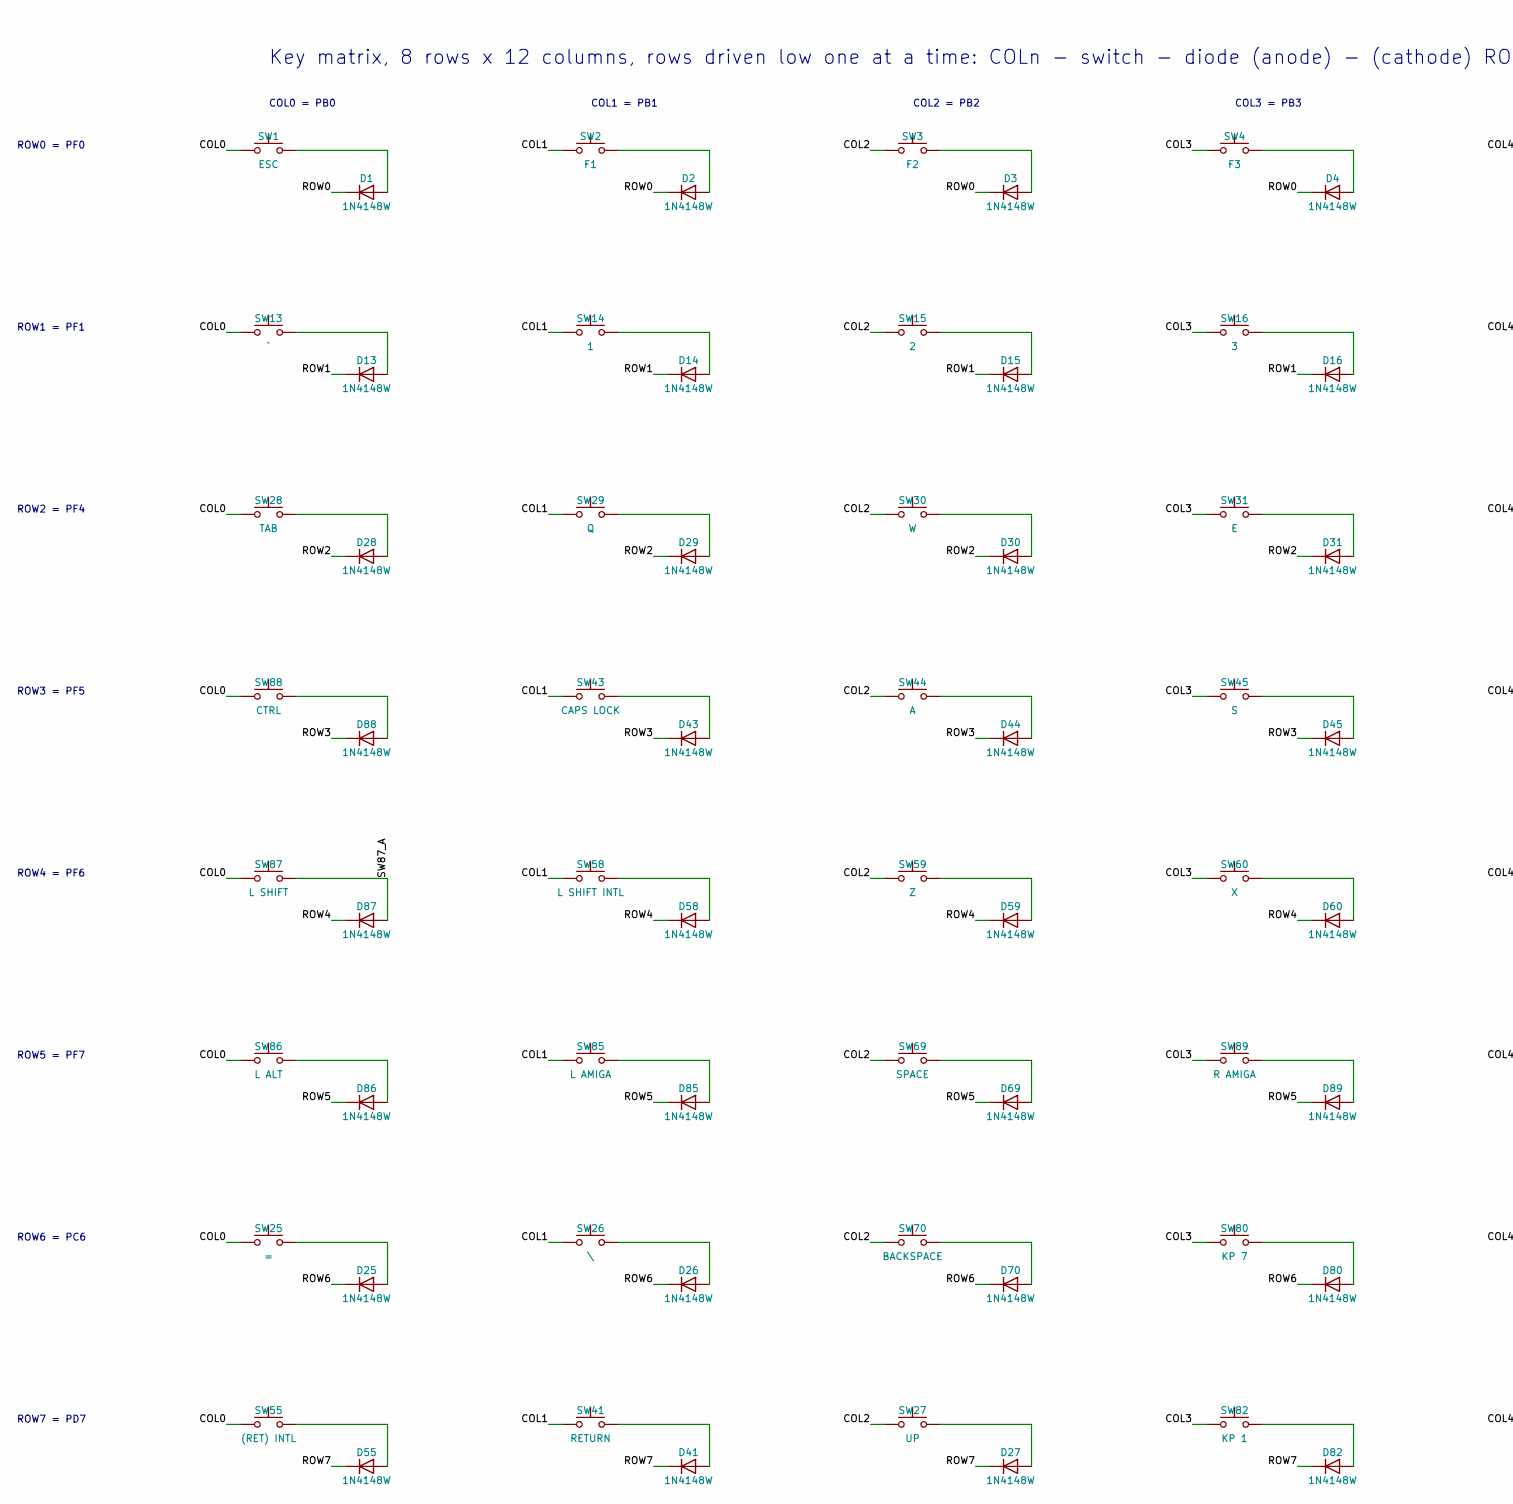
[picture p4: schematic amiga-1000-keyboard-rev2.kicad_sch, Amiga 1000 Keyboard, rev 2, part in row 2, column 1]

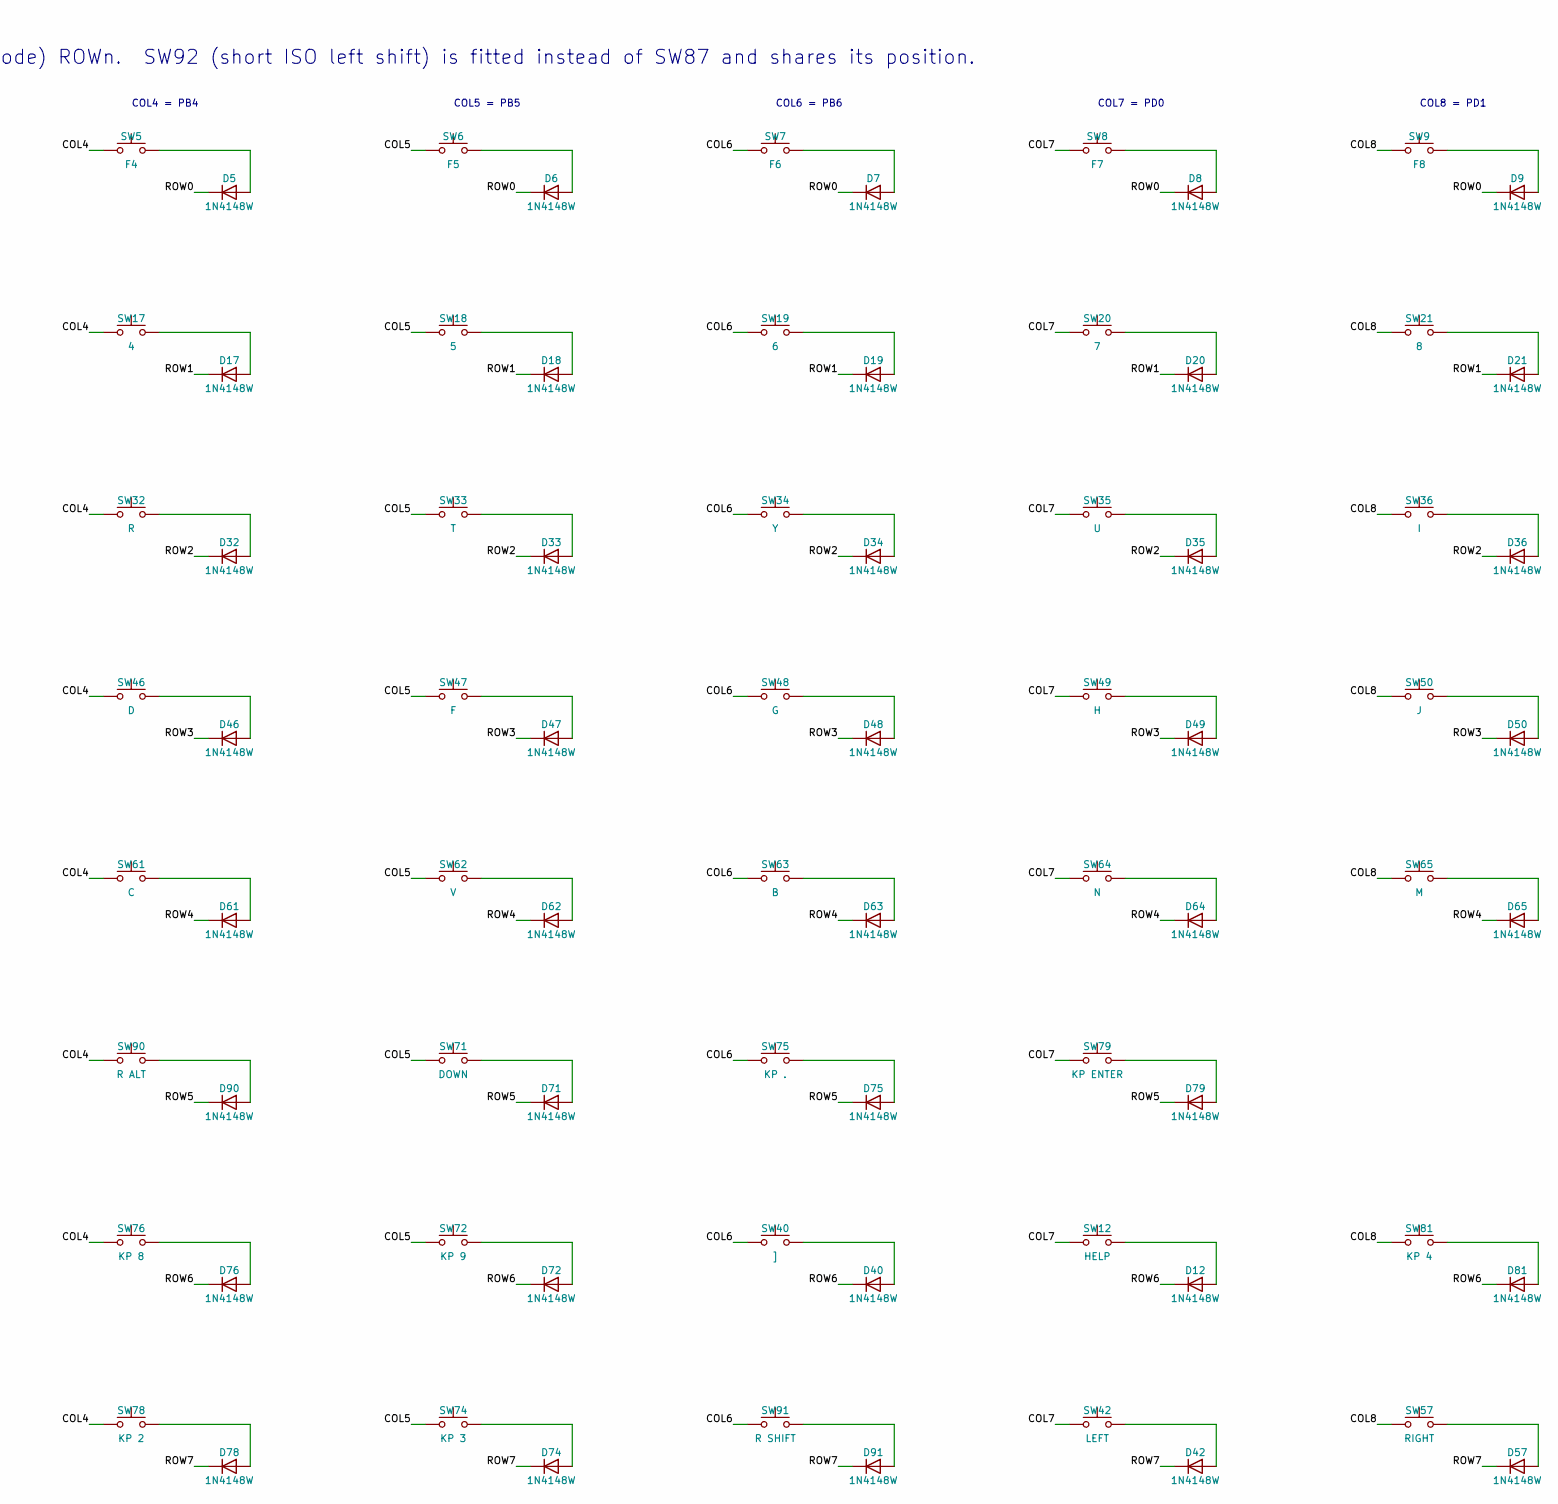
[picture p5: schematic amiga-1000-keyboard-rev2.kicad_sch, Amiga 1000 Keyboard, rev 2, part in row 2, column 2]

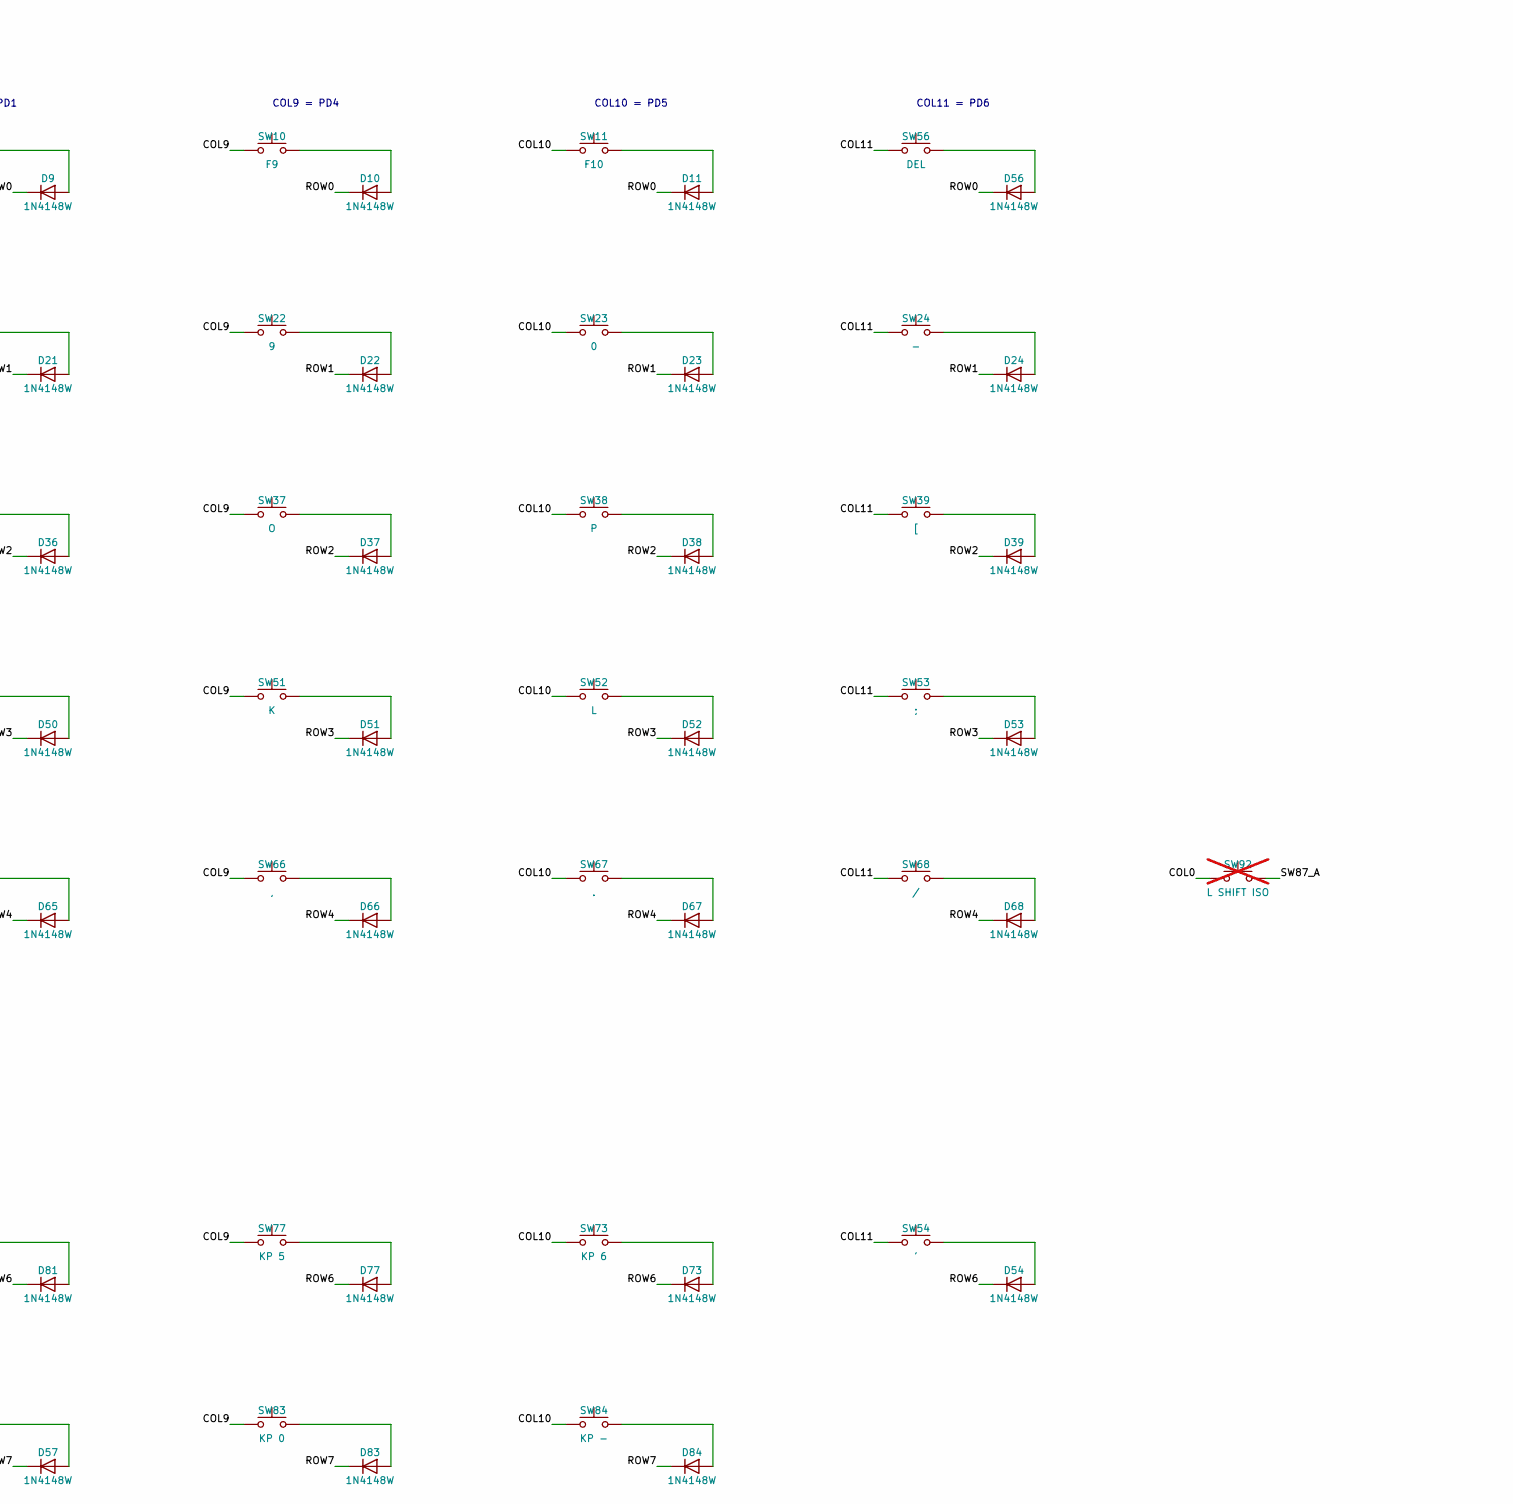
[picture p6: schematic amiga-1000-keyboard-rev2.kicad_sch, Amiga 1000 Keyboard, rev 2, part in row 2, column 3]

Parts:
C1, C2: 12pF; C_0402_1005Metric; Part 12 pF C0G 0402; LCSC C1547
C3, C4, C5, C6, C9: 100nF; C_0402_1005Metric; Part 100 nF X7R 0402; LCSC C1525
C7, C12: 10uF; C_0603_1608Metric; Part 10 uF X5R 10 V 0603; LCSC C19702
C8: 1uF; C_0402_1005Metric; Part 1 uF X5R 0402; LCSC C52923
C10, C11: 1uF; C_0402_1005Metric; Part 1 uF X5R 10 V 0402; LCSC C52923
C13, C14, C15: 1nF; C_0402_1005Metric; Part 1 nF X7R 0402; LCSC C1523; not fitted
D1, D2, D3, D4, D5, D6, D7, D8, D9, D10, D11, D12, D13, D14, D15, D16, D17, D18, D19, D20, D21, D22, D23, D24, D25, D26, D27, D28, D29, D30, D31, D32, D33, D34, D35, D36, D37, D38, D39, D40, D41, D42, D43, D44, D45, D46, D47, D48, D49, D50, D51, D52, D53, D54, D55, D56, D57, D58, D59, D60, D61, D62, D63, D64, D65, D66, D67, D68, D69, D70, D71, D72, D73, D74, D75, D76, D77, D78, D79, D80, D81, D82, D83, D84, D85, D86, D87, D88, D89, D90, D91: 1N4148W; D_SOD-123; Part 1N4148W SOD-123; LCSC C81598
D92: CAPS LOCK; MX_A1000_LED; Part 3 mm LED through a Cherry MX switch
F1: 500mA; Fuse_1206_3216Metric; Part 500 mA hold PTC fuse, 1206; LCSC C70077
FB1, FB2, FB3: FB; L_0603_1608Metric; Part Ferrite bead 600R@100MHz 0603; LCSC C1002
H1, H2, H3, H4, H5, H6, H7, H8, H9: Plate GND; MountingHole_3.8mm_Plate_GND
H10, H11, H12: Case screw; MountingHole_7.5mm_CaseClearance
J1: AMIGA; JST_PH_S4B-PH-SM4-TB_1x04-1MP_P2.00mm_Horizontal; Part JST PH 4-pin SMD right angle; LCSC C265102
J2: USB-C; USB_C_Receptacle_HRO_TYPE-C-31-M-12; Part HRO TYPE-C-31-M-12 USB-C receptacle; LCSC C165948
J3: ISP; PinHeader_2x03_P2.54mm_Vertical; Part AVR ISP header (recovery only); not fitted
JP1: RESET; SolderJumper-2_P1.3mm_Open_RoundedPad1.0x1.5mm; Part pads, shorted with tweezers
JP2: BOOT; SolderJumper-2_P1.3mm_Open_RoundedPad1.0x1.5mm; Part pads, shorted with tweezers
R1, R2, R5, R6: 10k; R_0402_1005Metric; Part 10k 1% 0402; LCSC C25744
R3: 330; R_0402_1005Metric; Part 330 1% 0402; LCSC C25104
R4: 33k; R_0402_1005Metric; Part 33k 1% 0402; LCSC C25779
R7, R8: 5.1k; R_0402_1005Metric; Part 5.1k 1% 0402; LCSC C25905
R9, R10: 22; R_0402_1005Metric; Part 22 1% 0402; LCSC C25092
SW1: ESC; MX_A1000_1U; Part Cherry MX (or compatible) keyswitch
SW2: F1; MX_A1000_1.25U; Part Cherry MX (or compatible) keyswitch
SW3: F2; MX_A1000_1.25U; Part Cherry MX (or compatible) keyswitch
SW4: F3; MX_A1000_1.25U; Part Cherry MX (or compatible) keyswitch
SW5: F4; MX_A1000_1.25U; Part Cherry MX (or compatible) keyswitch
SW6: F5; MX_A1000_1.25U; Part Cherry MX (or compatible) keyswitch
SW7: F6; MX_A1000_1.25U; Part Cherry MX (or compatible) keyswitch
SW8: F7; MX_A1000_1.25U; Part Cherry MX (or compatible) keyswitch
SW9: F8; MX_A1000_1.25U; Part Cherry MX (or compatible) keyswitch
SW10: F9; MX_A1000_1.25U; Part Cherry MX (or compatible) keyswitch
SW11: F10; MX_A1000_1.25U; Part Cherry MX (or compatible) keyswitch
SW12: HELP; MX_A1000_1U; Part Cherry MX (or compatible) keyswitch
SW13: `; MX_A1000_1.25U; Part Cherry MX (or compatible) keyswitch
SW14: 1; MX_A1000_1U; Part Cherry MX (or compatible) keyswitch
SW15: 2; MX_A1000_1U; Part Cherry MX (or compatible) keyswitch
SW16: 3; MX_A1000_1U; Part Cherry MX (or compatible) keyswitch
SW17: 4; MX_A1000_1U; Part Cherry MX (or compatible) keyswitch
SW18: 5; MX_A1000_1U; Part Cherry MX (or compatible) keyswitch
SW19: 6; MX_A1000_1U; Part Cherry MX (or compatible) keyswitch
SW20: 7; MX_A1000_1U; Part Cherry MX (or compatible) keyswitch
SW21: 8; MX_A1000_1U; Part Cherry MX (or compatible) keyswitch
SW22: 9; MX_A1000_1U; Part Cherry MX (or compatible) keyswitch
SW23: 0; MX_A1000_1U; Part Cherry MX (or compatible) keyswitch
SW24: -; MX_A1000_1U; Part Cherry MX (or compatible) keyswitch
SW25: =; MX_A1000_1U; Part Cherry MX (or compatible) keyswitch
SW26: \; MX_A1000_1U; Part Cherry MX (or compatible) keyswitch
SW27: UP; MX_A1000_1U; Part Cherry MX (or compatible) keyswitch
SW28: TAB; MX_A1000_1.75U; Part Cherry MX (or compatible) keyswitch
SW29: Q; MX_A1000_1U; Part Cherry MX (or compatible) keyswitch
SW30: W; MX_A1000_1U; Part Cherry MX (or compatible) keyswitch
SW31: E; MX_A1000_1U; Part Cherry MX (or compatible) keyswitch
SW32: R; MX_A1000_1U; Part Cherry MX (or compatible) keyswitch
SW33: T; MX_A1000_1U; Part Cherry MX (or compatible) keyswitch
SW34: Y; MX_A1000_1U; Part Cherry MX (or compatible) keyswitch
SW35: U; MX_A1000_1U; Part Cherry MX (or compatible) keyswitch
SW36: I; MX_A1000_1U; Part Cherry MX (or compatible) keyswitch
SW37: O; MX_A1000_1U; Part Cherry MX (or compatible) keyswitch
SW38: P; MX_A1000_1U; Part Cherry MX (or compatible) keyswitch
SW39: [; MX_A1000_1U; Part Cherry MX (or compatible) keyswitch
SW40: ]; MX_A1000_1U; Part Cherry MX (or compatible) keyswitch
SW41: RETURN; MX_A1000_Return; Part Cherry MX (or compatible) keyswitch
SW42: LEFT; MX_A1000_1U; Part Cherry MX (or compatible) keyswitch
SW43: CAPS LOCK; MX_A1000_1U; Part Cherry MX (or compatible) keyswitch
SW44: A; MX_A1000_1U; Part Cherry MX (or compatible) keyswitch
SW45: S; MX_A1000_1U; Part Cherry MX (or compatible) keyswitch
SW46: D; MX_A1000_1U; Part Cherry MX (or compatible) keyswitch
SW47: F; MX_A1000_1U; Part Cherry MX (or compatible) keyswitch
SW48: G; MX_A1000_1U; Part Cherry MX (or compatible) keyswitch
SW49: H; MX_A1000_1U; Part Cherry MX (or compatible) keyswitch
SW50: J; MX_A1000_1U; Part Cherry MX (or compatible) keyswitch
SW51: K; MX_A1000_1U; Part Cherry MX (or compatible) keyswitch
SW52: L; MX_A1000_1U; Part Cherry MX (or compatible) keyswitch
SW53: ;; MX_A1000_1U; Part Cherry MX (or compatible) keyswitch
SW54: '; MX_A1000_1U; Part Cherry MX (or compatible) keyswitch
SW55: (RET) INTL; MX_A1000_1U; Part Cherry MX (or compatible) keyswitch
SW56: DEL; MX_A1000_1U; Part Cherry MX (or compatible) keyswitch
SW57: RIGHT; MX_A1000_1U; Part Cherry MX (or compatible) keyswitch
SW58: L SHIFT INTL; MX_A1000_1U; Part Cherry MX (or compatible) keyswitch
SW59: Z; MX_A1000_1U; Part Cherry MX (or compatible) keyswitch
SW60: X; MX_A1000_1U; Part Cherry MX (or compatible) keyswitch
SW61: C; MX_A1000_1U; Part Cherry MX (or compatible) keyswitch
SW62: V; MX_A1000_1U; Part Cherry MX (or compatible) keyswitch
SW63: B; MX_A1000_1U; Part Cherry MX (or compatible) keyswitch
SW64: N; MX_A1000_1U; Part Cherry MX (or compatible) keyswitch
SW65: M; MX_A1000_1U; Part Cherry MX (or compatible) keyswitch
SW66: ,; MX_A1000_1U; Part Cherry MX (or compatible) keyswitch
SW67: .; MX_A1000_1U; Part Cherry MX (or compatible) keyswitch
SW68: /; MX_A1000_1U; Part Cherry MX (or compatible) keyswitch
SW69: SPACE; MX_A1000_7.5U; Part Cherry MX (or compatible) keyswitch
SW70: BACKSPACE; MX_A1000_1.75U; Part Cherry MX (or compatible) keyswitch
SW71: DOWN; MX_A1000_1U; Part Cherry MX (or compatible) keyswitch
SW72: KP 9; MX_A1000_1U; Part Cherry MX (or compatible) keyswitch
SW73: KP 6; MX_A1000_1U; Part Cherry MX (or compatible) keyswitch
SW74: KP 3; MX_A1000_1U; Part Cherry MX (or compatible) keyswitch
SW75: KP .; MX_A1000_1U; Part Cherry MX (or compatible) keyswitch
SW76: KP 8; MX_A1000_1U; Part Cherry MX (or compatible) keyswitch
SW77: KP 5; MX_A1000_1U; Part Cherry MX (or compatible) keyswitch
SW78: KP 2; MX_A1000_1U; Part Cherry MX (or compatible) keyswitch
SW79: KP ENTER; MX_A1000_2U; Part Cherry MX (or compatible) keyswitch
SW80: KP 7; MX_A1000_1U; Part Cherry MX (or compatible) keyswitch
SW81: KP 4; MX_A1000_1U; Part Cherry MX (or compatible) keyswitch
SW82: KP 1; MX_A1000_1U; Part Cherry MX (or compatible) keyswitch
SW83: KP 0; MX_A1000_2U; Part Cherry MX (or compatible) keyswitch
SW84: KP -; MX_A1000_1U; Part Cherry MX (or compatible) keyswitch
SW85: L AMIGA; MX_A1000_1.25U; Part Cherry MX (or compatible) keyswitch
SW86: L ALT; MX_A1000_1.25U; Part Cherry MX (or compatible) keyswitch
SW87: L SHIFT; MX_A1000_LShift; Part Cherry MX (or compatible) keyswitch
SW88: CTRL; MX_A1000_1U; Part Cherry MX (or compatible) keyswitch
SW89: R AMIGA; MX_A1000_1.25U; Part Cherry MX (or compatible) keyswitch
SW90: R ALT; MX_A1000_1.25U; Part Cherry MX (or compatible) keyswitch
SW91: R SHIFT; MX_A1000_2U; Part Cherry MX (or compatible) keyswitch
SW92: L SHIFT ISO; MX_A1000_LShift_ISO; Part Cherry MX (or compatible) keyswitch; not fitted
TP1: SPARE (PC7); TestPoint_Pad_D1.5mm; Part test pad
U1: ATmega32U4-AU; TQFP-44_10x10mm_P0.8mm; Part ATMEGA32U4-AU, TQFP-44; LCSC C44854
U2: TPS2116DRLR; SOT-583-8; Part TPS2116DRLR power mux; LCSC C3235557
U3: USBLC6-2SC6; SOT-23-6; Part USBLC6-2SC6 USB ESD protection; LCSC C7519
Y1: 16MHz; Crystal_SMD_3225-4Pin_3.2x2.5mm; Part 16 MHz crystal, 3225, CL 9 pF; LCSC C13738

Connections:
+5V: C3.1, C4.1, C5.1, C6.1, C7.1, C12.1, J3.2, R1.1, R2.1, R6.1, U1.2 (UVCC), U1.14 (VCC), U1.24 (AVCC), U1.34 (VCC), U1.44 (AVCC), U2.2 (VOUT), U2.7 (VOUT)
/AMIGA_PWR: R6.2, U1.1 (PE6), U2.8 (ST)
/AREF: C9.1, U1.42 (AREF)
/CAPS_LED: R3.1, U1.12 (PB7)
/CAPS_LED_A: D92.2 (A), R3.2
/CC1: J2.A5 (CC1), R7.1
/CC2: J2.B5 (CC2), R8.1
/COL0: SW1.1, SW13.1, SW25.1, SW28.1, SW55.1, SW86.1, SW87.1, SW88.1, SW92.1, U1.8 (PB0)
/COL1: J3.3, SW2.1, SW14.1, SW26.1, SW29.1, SW41.1, SW43.1, SW58.1, SW85.1, U1.9 (PB1)
/COL2: J3.4, SW3.1, SW15.1, SW27.1, SW30.1, SW44.1, SW59.1, SW69.1, SW70.1, U1.10 (PB2)
/COL3: J3.1, SW4.1, SW16.1, SW31.1, SW45.1, SW60.1, SW80.1, SW82.1, SW89.1, U1.11 (PB3)
/COL4: SW5.1, SW17.1, SW32.1, SW46.1, SW61.1, SW76.1, SW78.1, SW90.1, U1.28 (PB4)
/COL5: SW6.1, SW18.1, SW33.1, SW47.1, SW62.1, SW71.1, SW72.1, SW74.1, U1.29 (PB5)
/COL6: SW7.1, SW19.1, SW34.1, SW40.1, SW48.1, SW63.1, SW75.1, SW91.1, U1.30 (PB6)
/COL7: SW8.1, SW12.1, SW20.1, SW35.1, SW42.1, SW49.1, SW64.1, SW79.1, U1.18 (PD0)
/COL8: SW9.1, SW21.1, SW36.1, SW50.1, SW57.1, SW65.1, SW81.1, U1.19 (PD1)
/COL9: SW10.1, SW22.1, SW37.1, SW51.1, SW66.1, SW77.1, SW83.1, U1.25 (PD4)
/COL10: SW11.1, SW23.1, SW38.1, SW52.1, SW67.1, SW73.1, SW84.1, U1.22 (PD5)
/COL11: SW24.1, SW39.1, SW53.1, SW54.1, SW56.1, SW68.1, U1.26 (PD6)
/HWB: JP2.1 (A), R2.2, U1.33 (~HWB/PE2)
/KCLK: FB2.2, U1.20 (PD2)
/KCLK_EXT: C14.1, FB2.1, J1.3
/KDAT: FB3.2, U1.21 (PD3)
/KDAT_EXT: C15.1, FB3.1, J1.4
/PR1: R4.2, R5.1, U2.4 (PR1)
/RESET: J3.5, JP1.1 (A), R1.2, U1.13 (~RESET)
/ROW0: D1.1 (K), D2.1 (K), D3.1 (K), D4.1 (K), D5.1 (K), D6.1 (K), D7.1 (K), D8.1 (K), D9.1 (K), D10.1 (K), D11.1 (K), D56.1 (K), U1.41 (PF0)
/ROW1: D13.1 (K), D14.1 (K), D15.1 (K), D16.1 (K), D17.1 (K), D18.1 (K), D19.1 (K), D20.1 (K), D21.1 (K), D22.1 (K), D23.1 (K), D24.1 (K), U1.40 (PF1)
/ROW2: D28.1 (K), D29.1 (K), D30.1 (K), D31.1 (K), D32.1 (K), D33.1 (K), D34.1 (K), D35.1 (K), D36.1 (K), D37.1 (K), D38.1 (K), D39.1 (K), U1.39 (PF4)
/ROW3: D43.1 (K), D44.1 (K), D45.1 (K), D46.1 (K), D47.1 (K), D48.1 (K), D49.1 (K), D50.1 (K), D51.1 (K), D52.1 (K), D53.1 (K), D88.1 (K), U1.38 (PF5)
/ROW4: D58.1 (K), D59.1 (K), D60.1 (K), D61.1 (K), D62.1 (K), D63.1 (K), D64.1 (K), D65.1 (K), D66.1 (K), D67.1 (K), D68.1 (K), D87.1 (K), U1.37 (PF6)
/ROW5: D69.1 (K), D71.1 (K), D75.1 (K), D79.1 (K), D85.1 (K), D86.1 (K), D89.1 (K), D90.1 (K), U1.36 (PF7)
/ROW6: D12.1 (K), D25.1 (K), D26.1 (K), D40.1 (K), D54.1 (K), D70.1 (K), D72.1 (K), D73.1 (K), D76.1 (K), D77.1 (K), D80.1 (K), D81.1 (K), U1.31 (PC6)
/ROW7: D27.1 (K), D41.1 (K), D42.1 (K), D55.1 (K), D57.1 (K), D74.1 (K), D78.1 (K), D82.1 (K), D83.1 (K), D84.1 (K), D91.1 (K), U1.27 (PD7)
/SPARE: TP1.1, U1.32 (PC7)
/SW87_A: D87.2 (A), SW87.2, SW92.2
/UCAP: C8.1, U1.6 (UCAP)
/USB_DN: J2.A7 (D-), J2.B7 (D-), R10.1, U3.3 (I/O2), U3.4 (I/O2)
/USB_DN_MCU: R10.2, U1.3 (D-)
/USB_DP: J2.A6 (D+), J2.B6 (D+), R9.1, U3.1 (I/O1), U3.6 (I/O1)
/USB_DP_MCU: R9.2, U1.4 (D+)
/VBUS: C11.1, F1.2, U1.7 (VBUS), U2.6 (VIN2), U3.5 (VBUS)
/VBUS_IN: F1.1, J2.A4 (VBUS), J2.A9 (VBUS), J2.B4 (VBUS), J2.B9 (VBUS)
/VCC_AMIGA: C10.1, FB1.2, R4.1, U2.3 (VIN1), U2.5 (MODE)
/VCC_EXT: C13.1, FB1.1, J1.2
/XTAL1: C1.1, U1.17 (XTAL1), Y1.1
/XTAL2: C2.1, U1.16 (XTAL2), Y1.3
GND: C1.2, C2.2, C3.2, C4.2, C5.2, C6.2, C7.2, C8.2, C9.2, C10.2, C11.2, C12.2, C13.2, C14.2, C15.2, D92.1 (K), H1.1, H2.1, H3.1, H4.1, H5.1, H6.1, H7.1, H8.1, H9.1, J1.1, J2.A1 (GND), J2.A12 (GND), J2.B1 (GND), J2.B12 (GND), J2.SH (SHIELD), J3.6, JP1.2 (B), JP2.2 (B), R5.2, R7.2, R8.2, U1.5 (UGND), U1.15 (GND), U1.23 (GND), U1.35 (GND), U1.43 (GND), U2.1 (GND), U3.2 (GND), Y1.2 (G), Y1.4 (G)
unnamed: D1.2 (A), SW1.2
unnamed: D2.2 (A), SW2.2
unnamed: D3.2 (A), SW3.2
unnamed: D4.2 (A), SW4.2
unnamed: D5.2 (A), SW5.2
unnamed: D6.2 (A), SW6.2
unnamed: D7.2 (A), SW7.2
unnamed: D8.2 (A), SW8.2
unnamed: D9.2 (A), SW9.2
unnamed: D10.2 (A), SW10.2
unnamed: D11.2 (A), SW11.2
unnamed: D12.2 (A), SW12.2
unnamed: D13.2 (A), SW13.2
unnamed: D14.2 (A), SW14.2
unnamed: D15.2 (A), SW15.2
unnamed: D16.2 (A), SW16.2
unnamed: D17.2 (A), SW17.2
unnamed: D18.2 (A), SW18.2
unnamed: D19.2 (A), SW19.2
unnamed: D20.2 (A), SW20.2
unnamed: D21.2 (A), SW21.2
unnamed: D22.2 (A), SW22.2
unnamed: D23.2 (A), SW23.2
unnamed: D24.2 (A), SW24.2
unnamed: D25.2 (A), SW25.2
unnamed: D26.2 (A), SW26.2
unnamed: D27.2 (A), SW27.2
unnamed: D28.2 (A), SW28.2
unnamed: D29.2 (A), SW29.2
unnamed: D30.2 (A), SW30.2
unnamed: D31.2 (A), SW31.2
unnamed: D32.2 (A), SW32.2
unnamed: D33.2 (A), SW33.2
unnamed: D34.2 (A), SW34.2
unnamed: D35.2 (A), SW35.2
unnamed: D36.2 (A), SW36.2
unnamed: D37.2 (A), SW37.2
unnamed: D38.2 (A), SW38.2
unnamed: D39.2 (A), SW39.2
unnamed: D40.2 (A), SW40.2
unnamed: D41.2 (A), SW41.2
unnamed: D42.2 (A), SW42.2
unnamed: D43.2 (A), SW43.2
unnamed: D44.2 (A), SW44.2
unnamed: D45.2 (A), SW45.2
unnamed: D46.2 (A), SW46.2
unnamed: D47.2 (A), SW47.2
unnamed: D48.2 (A), SW48.2
unnamed: D49.2 (A), SW49.2
unnamed: D50.2 (A), SW50.2
unnamed: D51.2 (A), SW51.2
unnamed: D52.2 (A), SW52.2
unnamed: D53.2 (A), SW53.2
unnamed: D54.2 (A), SW54.2
unnamed: D55.2 (A), SW55.2
unnamed: D56.2 (A), SW56.2
unnamed: D57.2 (A), SW57.2
unnamed: D58.2 (A), SW58.2
unnamed: D59.2 (A), SW59.2
unnamed: D60.2 (A), SW60.2
unnamed: D61.2 (A), SW61.2
unnamed: D62.2 (A), SW62.2
unnamed: D63.2 (A), SW63.2
unnamed: D64.2 (A), SW64.2
unnamed: D65.2 (A), SW65.2
unnamed: D66.2 (A), SW66.2
unnamed: D67.2 (A), SW67.2
unnamed: D68.2 (A), SW68.2
unnamed: D69.2 (A), SW69.2
unnamed: D70.2 (A), SW70.2
unnamed: D71.2 (A), SW71.2
unnamed: D72.2 (A), SW72.2
unnamed: D73.2 (A), SW73.2
unnamed: D74.2 (A), SW74.2
unnamed: D75.2 (A), SW75.2
unnamed: D76.2 (A), SW76.2
unnamed: D77.2 (A), SW77.2
unnamed: D78.2 (A), SW78.2
unnamed: D79.2 (A), SW79.2
unnamed: D80.2 (A), SW80.2
unnamed: D81.2 (A), SW81.2
unnamed: D82.2 (A), SW82.2
unnamed: D83.2 (A), SW83.2
unnamed: D84.2 (A), SW84.2
unnamed: D85.2 (A), SW85.2
unnamed: D86.2 (A), SW86.2
unnamed: D88.2 (A), SW88.2
unnamed: D89.2 (A), SW89.2
unnamed: D90.2 (A), SW90.2
unnamed: D91.2 (A), SW91.2

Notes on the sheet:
Controller: ATmega32U4, 16 MHz.
Power: the Amiga 5 V (VIN1) has priority; USB VBUS (VIN2) takes over below about 4.3 V.
USB-C (USB 2.0 device): ESD protection, 500 mA fuse, 22R series resistors.
Amiga keyboard cable to the 4P4C jack. KCLK and KDAT are open drain: the firmware only pulls them low.
Mounting holes: H1-H9 screw the plate down and ground it; H10-H12 clear the case screws.
Key matrix, 8 rows x 12 columns, rows driven low one at a time: COLn - switch - diode (anode) - (cathode) ROWn. SW92 (short ISO left shift) is fitted instead of SW87 and shares its position.
ROW0 = PF0
ROW1 = PF1
ROW2 = PF4
ROW3 = PF5
ROW4 = PF6
ROW5 = PF7
ROW6 = PC6
ROW7 = PD7
COL0 = PB0
COL1 = PB1
COL2 = PB2
COL3 = PB3
COL4 = PB4
COL5 = PB5
COL6 = PB6
COL7 = PD0
COL8 = PD1
COL9 = PD4
COL10 = PD5
COL11 = PD6

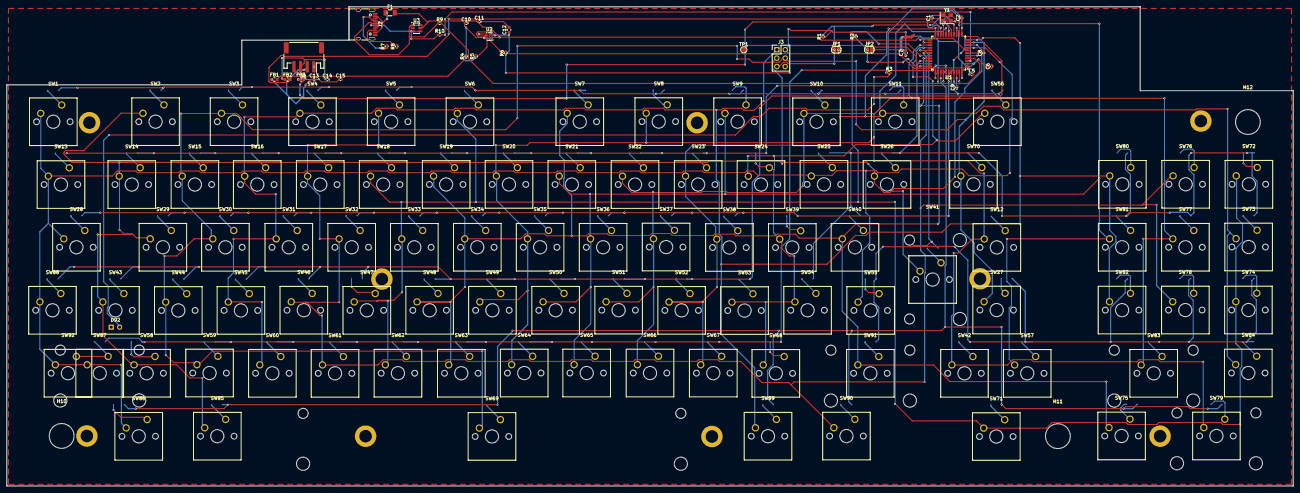
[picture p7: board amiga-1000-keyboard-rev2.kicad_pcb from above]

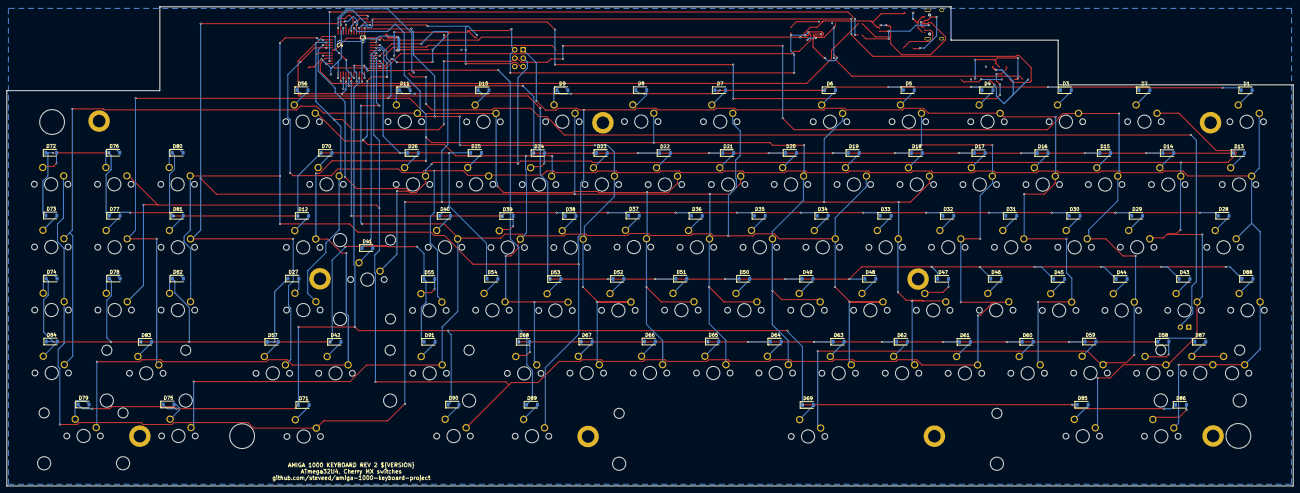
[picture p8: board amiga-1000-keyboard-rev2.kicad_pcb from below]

Board: 2 copper layers, 389.2 x 145.0 mm, 235 parts (93 on the bottom side), 138 nets.

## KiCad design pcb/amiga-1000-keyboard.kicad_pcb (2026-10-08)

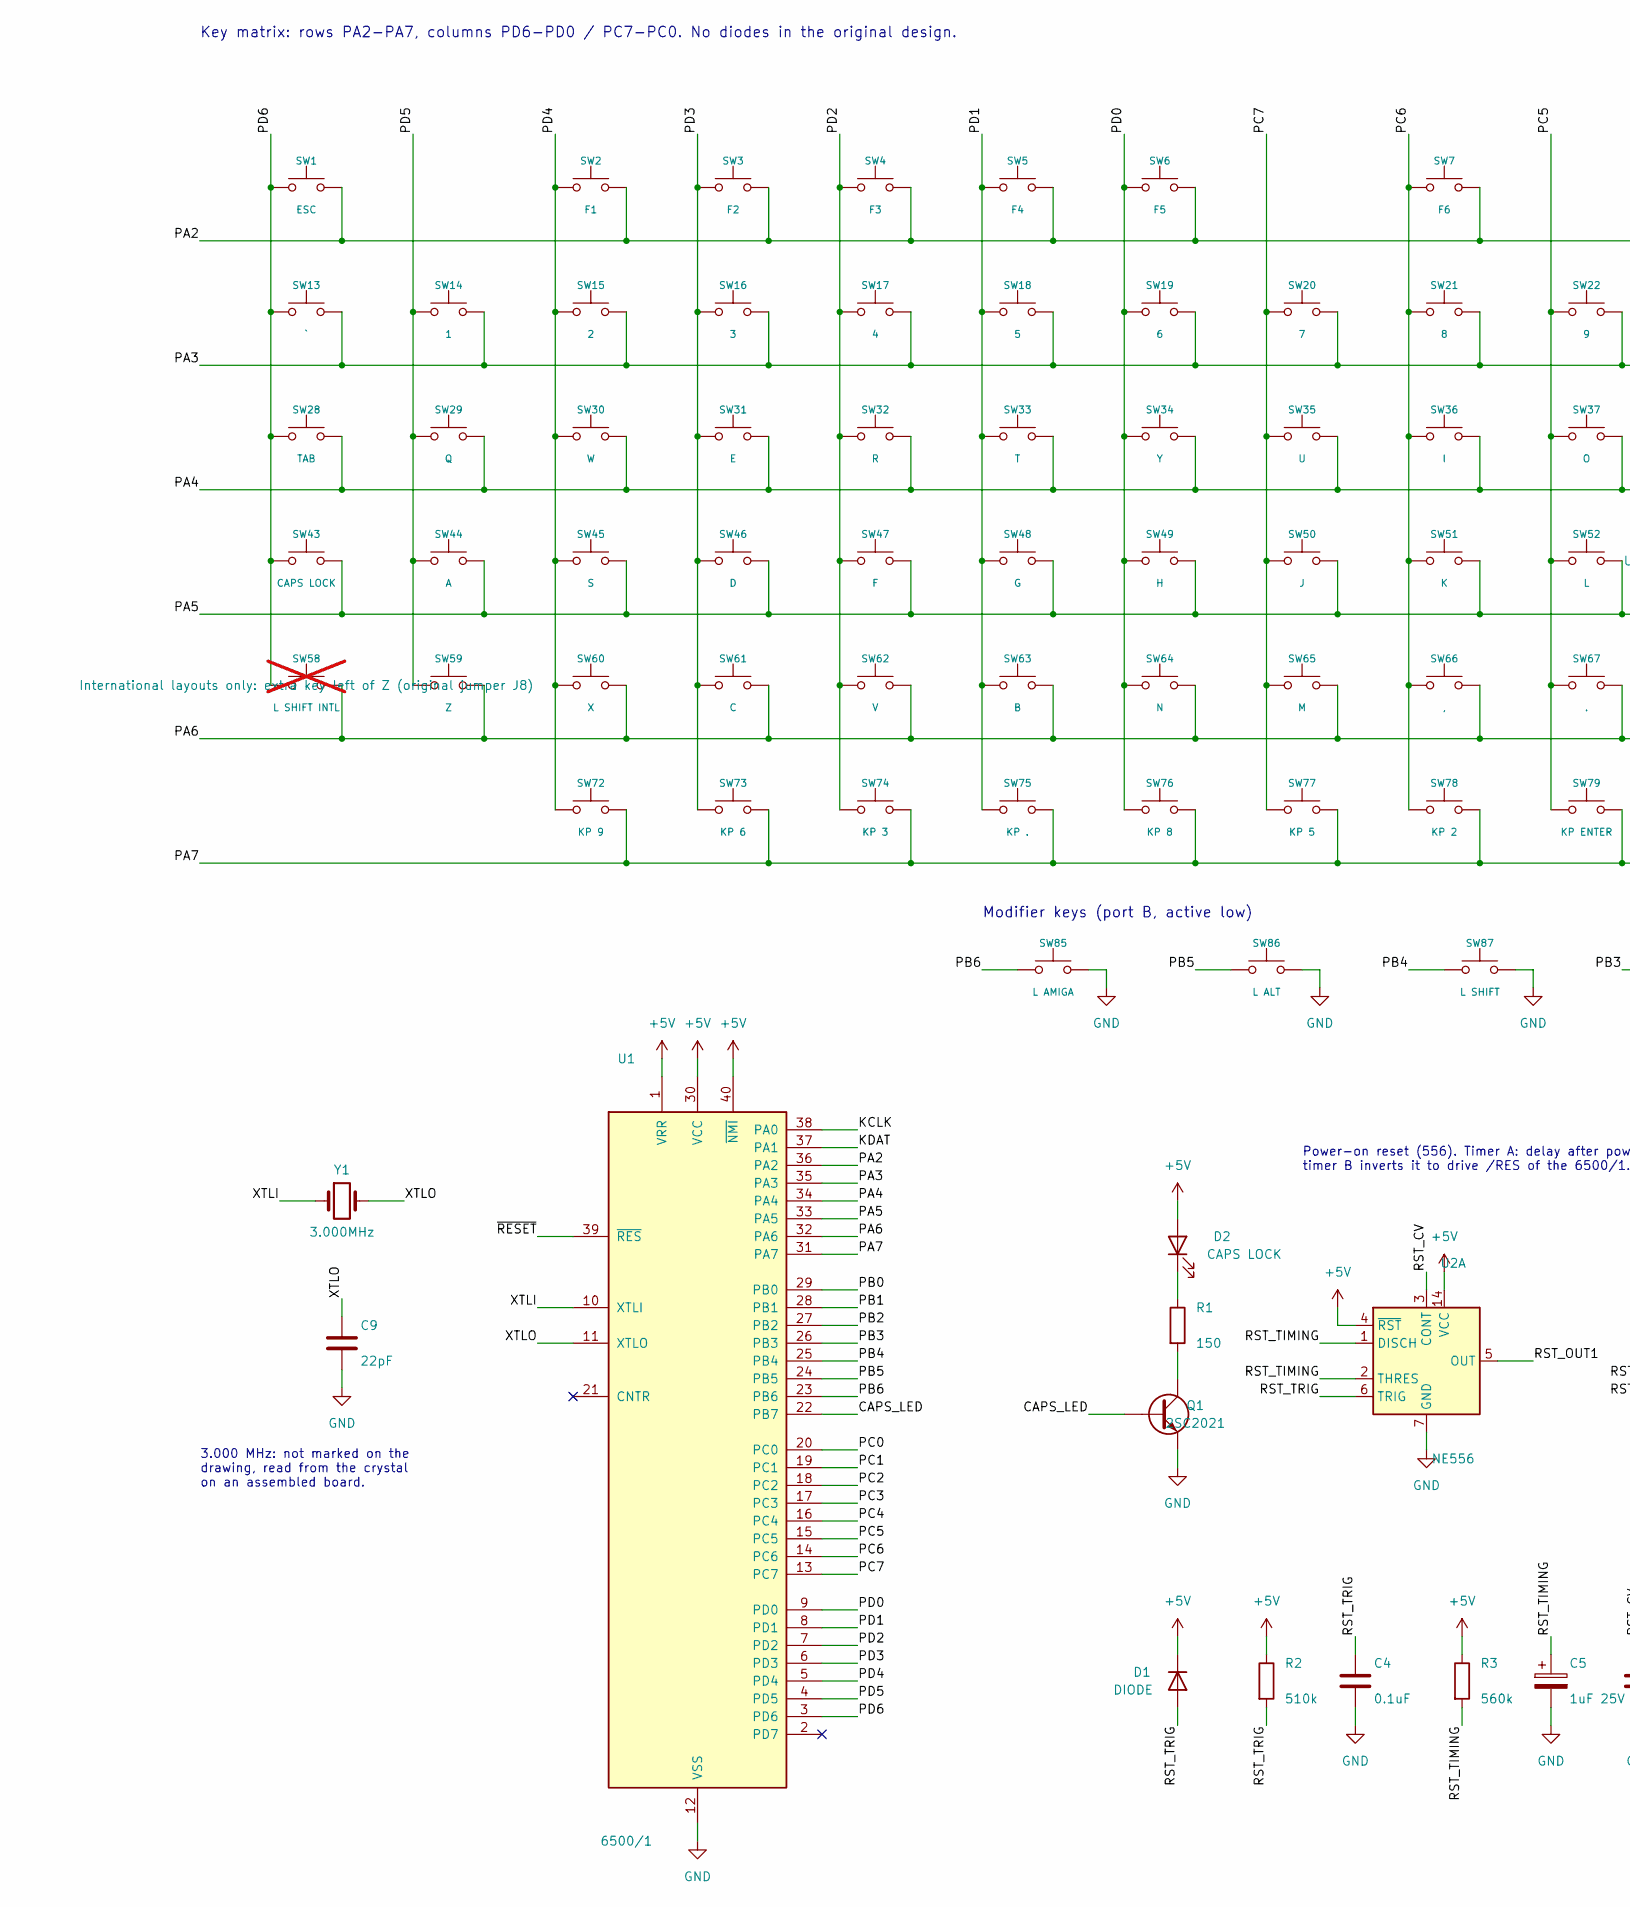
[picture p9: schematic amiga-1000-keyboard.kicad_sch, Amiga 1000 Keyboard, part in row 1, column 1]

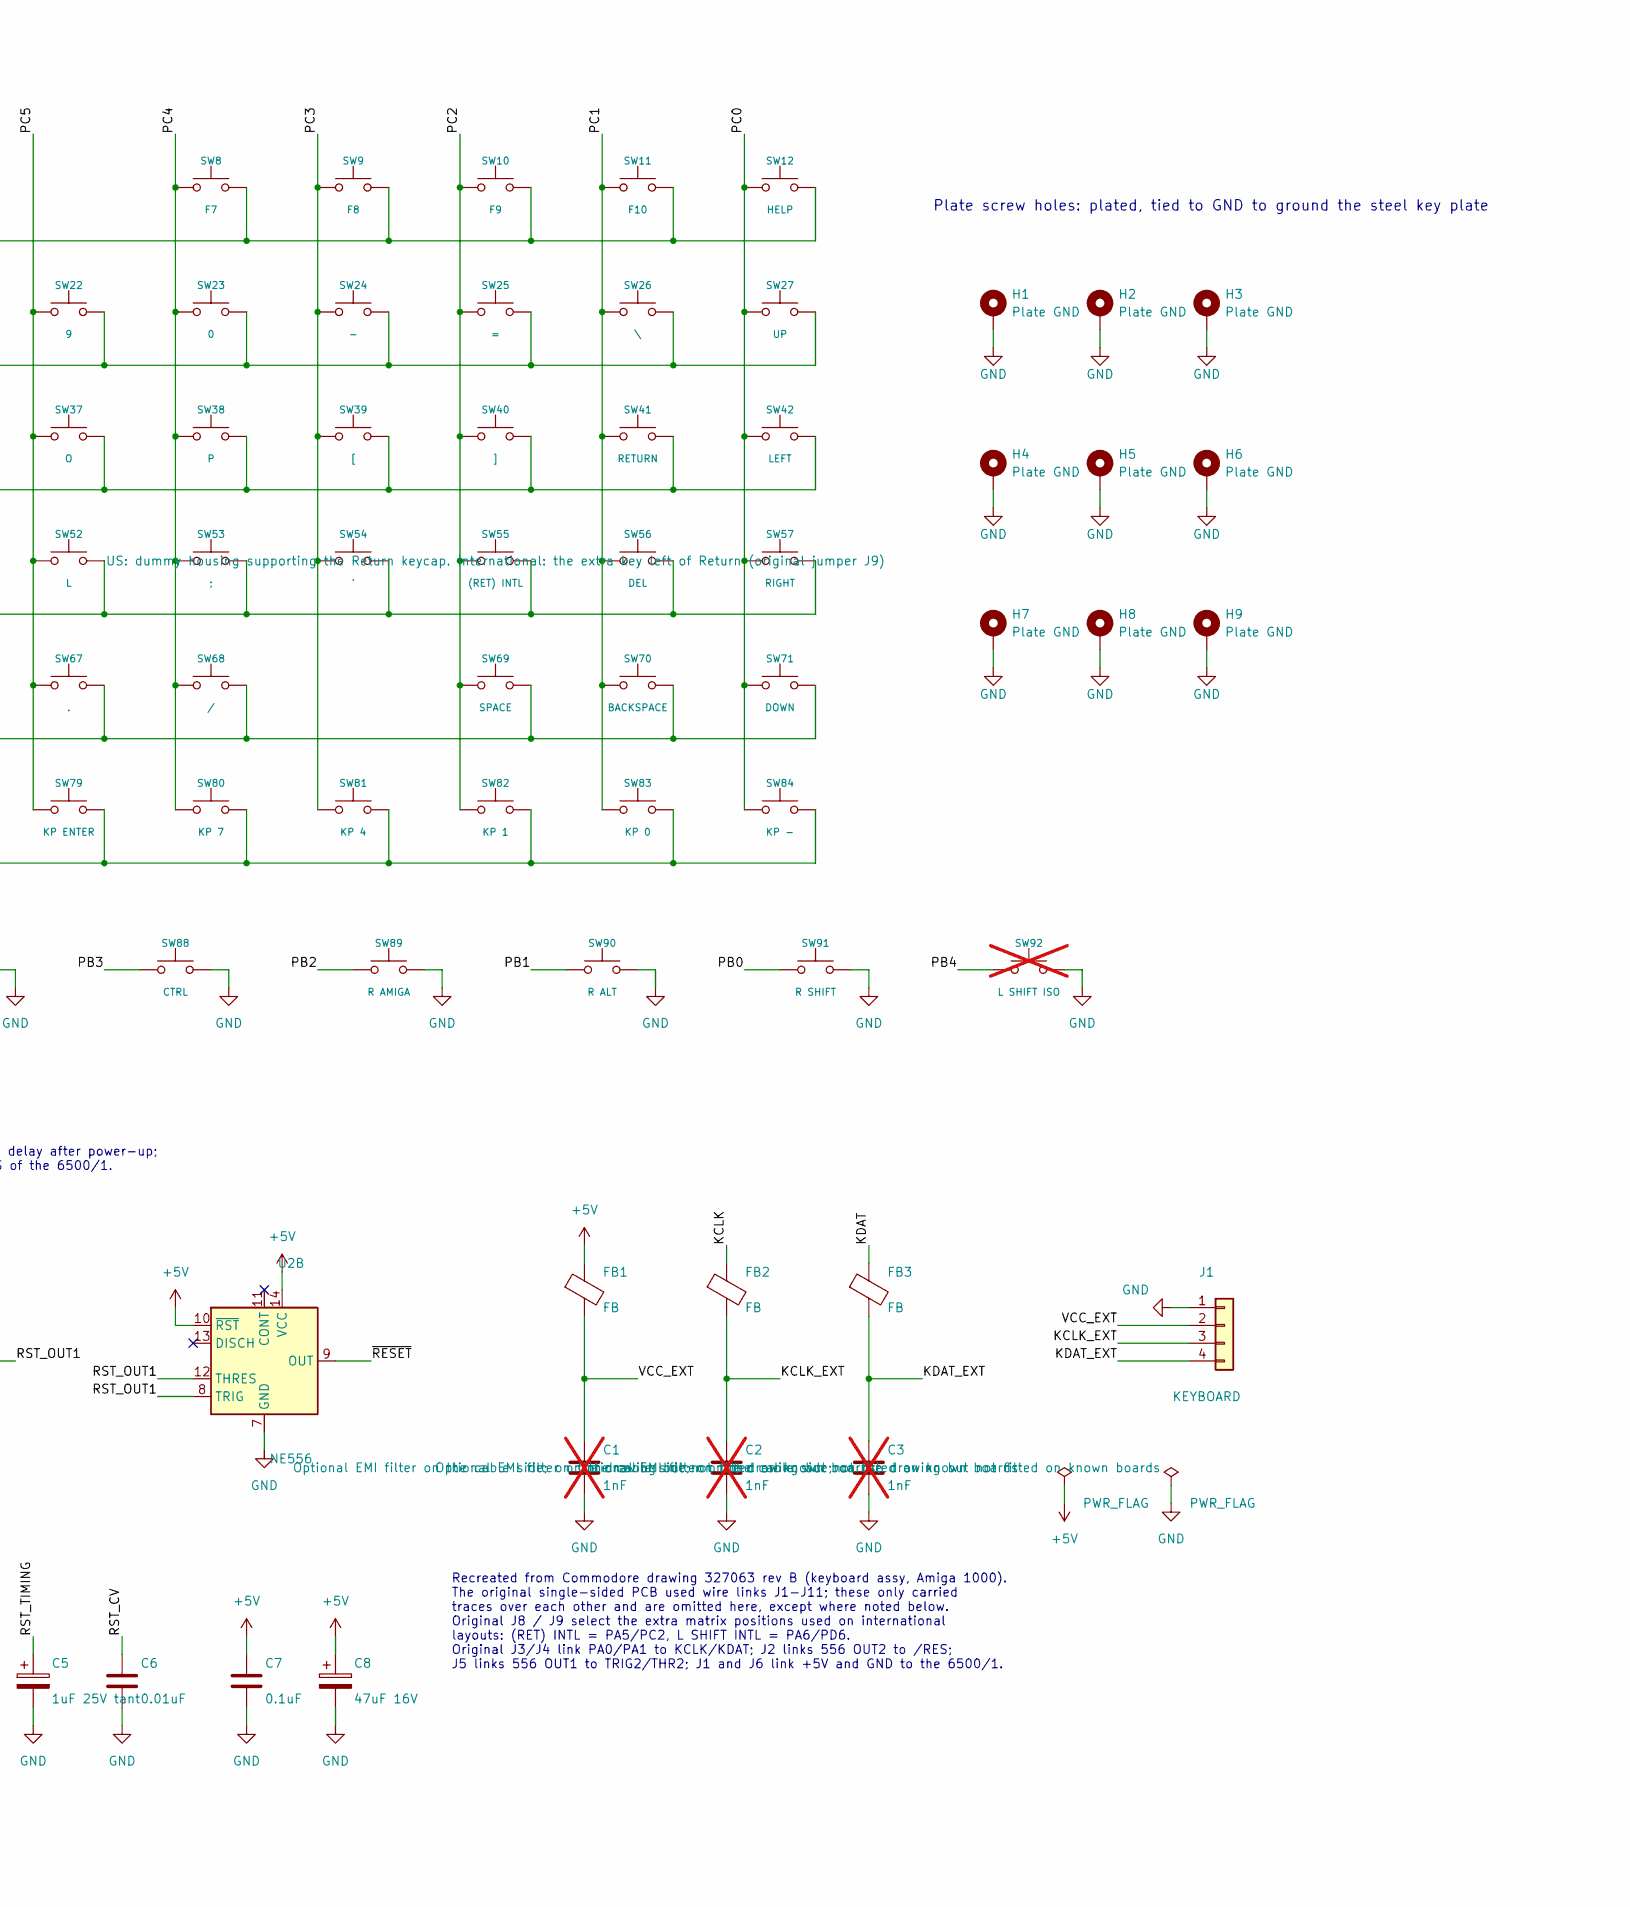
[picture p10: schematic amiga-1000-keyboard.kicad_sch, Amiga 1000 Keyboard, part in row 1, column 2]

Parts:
C1, C2, C3: 1nF; C_Disc_D5.0mm_W2.5mm_P5.00mm; Part 1nF 50V ceramic disc, 5 mm; not fitted
C4, C7: 0.1uF; C_Disc_D5.0mm_W2.5mm_P5.00mm; Part 100nF 50V ceramic disc, 5 mm
C5: 1uF 25V tant; CP_Radial_Tantal_D4.5mm_P2.50mm; Part 1uF 25V tantalum, 2.5 mm
C6: 0.01uF; C_Disc_D5.0mm_W2.5mm_P5.00mm; Part 10nF 50V ceramic disc, 5 mm
C8: 47uF 16V; CP_Radial_D5.0mm_P2.00mm; Part 47uF 16V electrolytic, 5 mm dia, 2 mm
C9: 22pF; C_Disc_D5.0mm_W2.5mm_P5.00mm; Part 22pF 50V C0G ceramic disc, 5 mm
D1: DIODE; D_DO-35_SOD27_P7.62mm_Horizontal; Part 1N4148 small-signal diode, DO-35 (origi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
D2: CAPS LOCK; Mitsumi_A1000_CapsLock_LED; Part LED built into the Caps Lock switch (no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
FB1, FB2, FB3: FB; L_Axial_L9.5mm_D4.0mm_P12.70mm_Horizontal_Fastron_SMCC; Part Axial ferrite bead, e.g. Fair-Rite 2743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
H1, H2, H3, H4, H5, H6, H7, H8, H9: Plate GND; MountingHole_3.8mm_Plate_GND
J1: KEYBOARD; PinHeader_1x04_P2.54mm_Vertical; Part Original 4-wire cable soldered in (or a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
Q1: 2SC2021; TO-92_Inline_Wide_ECB; Part 2SC2021 (Rohm SPT, original) or 2SC1815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
R1: 150; R_Axial_DIN0207_L6.3mm_D2.5mm_P10.16mm_Horizontal; Part 150R 1/4W axial
R2: 510k; R_Axial_DIN0207_L6.3mm_D2.5mm_P10.16mm_Horizontal; Part 510K 1/4W axial
R3: 560k; R_Axial_DIN0207_L6.3mm_D2.5mm_P10.16mm_Horizontal; Part 560K 1/4W axial
SW1: ESC; Mitsumi_A1000_Switch; Part Mitsumi standard mechanical Type 2 (KCT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
SW2: F1; Mitsumi_A1000_Switch; Part Mitsumi standard mechanical Type 2 (KCT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
SW3: F2; Mitsumi_A1000_Switch; Part Mitsumi standard mechanical Type 2 (KCT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
SW4: F3; Mitsumi_A1000_Switch; Part Mitsumi standard mechanical Type 2 (KCT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
SW5: F4; Mitsumi_A1000_Switch; Part Mitsumi standard mechanical Type 2 (KCT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
SW6: F5; Mitsumi_A1000_Switch; Part Mitsumi standard mechanical Type 2 (KCT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
SW7: F6; Mitsumi_A1000_Switch; Part Mitsumi standard mechanical Type 2 (KCT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
SW8: F7; Mitsumi_A1000_Switch; Part Mitsumi standard mechanical Type 2 (KCT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
SW9: F8; Mitsumi_A1000_Switch; Part Mitsumi standard mechanical Type 2 (KCT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
SW10: F9; Mitsumi_A1000_Switch; Part Mitsumi standard mechanical Type 2 (KCT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
SW11: F10; Mitsumi_A1000_Switch; Part Mitsumi standard mechanical Type 2 (KCT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
SW12: HELP; Mitsumi_A1000_Switch; Part Mitsumi standard mechanical Type 2 (KCT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
SW13: `; Mitsumi_A1000_Switch; Part Mitsumi standard mechanical Type 2 (KCT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
SW14: 1; Mitsumi_A1000_Switch; Part Mitsumi standard mechanical Type 2 (KCT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
SW15: 2; Mitsumi_A1000_Switch; Part Mitsumi standard mechanical Type 2 (KCT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
SW16: 3; Mitsumi_A1000_Switch; Part Mitsumi standard mechanical Type 2 (KCT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
SW17: 4; Mitsumi_A1000_Switch; Part Mitsumi standard mechanical Type 2 (KCT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
SW18: 5; Mitsumi_A1000_Switch; Part Mitsumi standard mechanical Type 2 (KCT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
SW19: 6; Mitsumi_A1000_Switch; Part Mitsumi standard mechanical Type 2 (KCT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
SW20: 7; Mitsumi_A1000_Switch; Part Mitsumi standard mechanical Type 2 (KCT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
SW21: 8; Mitsumi_A1000_Switch; Part Mitsumi standard mechanical Type 2 (KCT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
SW22: 9; Mitsumi_A1000_Switch; Part Mitsumi standard mechanical Type 2 (KCT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
SW23: 0; Mitsumi_A1000_Switch; Part Mitsumi standard mechanical Type 2 (KCT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
SW24: -; Mitsumi_A1000_Switch; Part Mitsumi standard mechanical Type 2 (KCT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
SW25: =; Mitsumi_A1000_Switch; Part Mitsumi standard mechanical Type 2 (KCT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
SW26: \; Mitsumi_A1000_Switch; Part Mitsumi standard mechanical Type 2 (KCT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
SW27: UP; Mitsumi_A1000_Switch; Part Mitsumi standard mechanical Type 2 (KCT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
SW28: TAB; Mitsumi_A1000_Switch; Part Mitsumi standard mechanical Type 2 (KCT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
SW29: Q; Mitsumi_A1000_Switch; Part Mitsumi standard mechanical Type 2 (KCT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
SW30: W; Mitsumi_A1000_Switch; Part Mitsumi standard mechanical Type 2 (KCT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
SW31: E; Mitsumi_A1000_Switch; Part Mitsumi standard mechanical Type 2 (KCT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
SW32: R; Mitsumi_A1000_Switch; Part Mitsumi standard mechanical Type 2 (KCT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
SW33: T; Mitsumi_A1000_Switch; Part Mitsumi standard mechanical Type 2 (KCT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
SW34: Y; Mitsumi_A1000_Switch; Part Mitsumi standard mechanical Type 2 (KCT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
SW35: U; Mitsumi_A1000_Switch; Part Mitsumi standard mechanical Type 2 (KCT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
SW36: I; Mitsumi_A1000_Switch; Part Mitsumi standard mechanical Type 2 (KCT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
SW37: O; Mitsumi_A1000_Switch; Part Mitsumi standard mechanical Type 2 (KCT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
SW38: P; Mitsumi_A1000_Switch; Part Mitsumi standard mechanical Type 2 (KCT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
SW39: [; Mitsumi_A1000_Switch; Part Mitsumi standard mechanical Type 2 (KCT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
SW40: ]; Mitsumi_A1000_Switch; Part Mitsumi standard mechanical Type 2 (KCT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
SW41: RETURN; Mitsumi_A1000_Switch; Part Mitsumi standard mechanical Type 2 (KCT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
SW42: LEFT; Mitsumi_A1000_Switch; Part Mitsumi standard mechanical Type 2 (KCT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
SW43: CAPS LOCK; Mitsumi_A1000_Switch; Part Mitsumi standard mechanical Type 2 (KCT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
SW44: A; Mitsumi_A1000_Switch; Part Mitsumi standard mechanical Type 2 (KCT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
SW45: S; Mitsumi_A1000_Switch; Part Mitsumi standard mechanical Type 2 (KCT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
SW46: D; Mitsumi_A1000_Switch; Part Mitsumi standard mechanical Type 2 (KCT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
SW47: F; Mitsumi_A1000_Switch; Part Mitsumi standard mechanical Type 2 (KCT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
SW48: G; Mitsumi_A1000_Switch; Part Mitsumi standard mechanical Type 2 (KCT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
SW49: H; Mitsumi_A1000_Switch; Part Mitsumi standard mechanical Type 2 (KCT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
SW50: J; Mitsumi_A1000_Switch; Part Mitsumi standard mechanical Type 2 (KCT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
SW51: K; Mitsumi_A1000_Switch; Part Mitsumi standard mechanical Type 2 (KCT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
SW52: L; Mitsumi_A1000_Switch; Part Mitsumi standard mechanical Type 2 (KCT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
SW53: ;; Mitsumi_A1000_Switch; Part Mitsumi standard mechanical Type 2 (KCT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
SW54: '; Mitsumi_A1000_Switch; Part Mitsumi standard mechanical Type 2 (KCT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
SW55: (RET) INTL; Mitsumi_A1000_Switch; Part Dummy Mitsumi housing (one leg, no spri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
SW56: DEL; Mitsumi_A1000_Switch; Part Mitsumi standard mechanical Type 2 (KCT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
SW57: RIGHT; Mitsumi_A1000_Switch; Part Mitsumi standard mechanical Type 2 (KCT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
SW58: L SHIFT INTL; Mitsumi_A1000_Switch; Part Mitsumi standard mechanical Type 2 (KCT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; not fitted
SW59: Z; Mitsumi_A1000_Switch; Part Mitsumi standard mechanical Type 2 (KCT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
SW60: X; Mitsumi_A1000_Switch; Part Mitsumi standard mechanical Type 2 (KCT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
SW61: C; Mitsumi_A1000_Switch; Part Mitsumi standard mechanical Type 2 (KCT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
SW62: V; Mitsumi_A1000_Switch; Part Mitsumi standard mechanical Type 2 (KCT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
SW63: B; Mitsumi_A1000_Switch; Part Mitsumi standard mechanical Type 2 (KCT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
SW64: N; Mitsumi_A1000_Switch; Part Mitsumi standard mechanical Type 2 (KCT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
SW65: M; Mitsumi_A1000_Switch; Part Mitsumi standard mechanical Type 2 (KCT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
SW66: ,; Mitsumi_A1000_Switch; Part Mitsumi standard mechanical Type 2 (KCT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
SW67: .; Mitsumi_A1000_Switch; Part Mitsumi standard mechanical Type 2 (KCT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
SW68: /; Mitsumi_A1000_Switch; Part Mitsumi standard mechanical Type 2 (KCT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
SW69: SPACE; Mitsumi_A1000_Switch; Part Mitsumi standard mechanical Type 2 (KCT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
SW70: BACKSPACE; Mitsumi_A1000_Switch; Part Mitsumi standard mechanical Type 2 (KCT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
SW71: DOWN; Mitsumi_A1000_Switch; Part Mitsumi standard mechanical Type 2 (KCT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
SW72: KP 9; Mitsumi_A1000_Switch; Part Mitsumi standard mechanical Type 2 (KCT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
SW73: KP 6; Mitsumi_A1000_Switch; Part Mitsumi standard mechanical Type 2 (KCT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
SW74: KP 3; Mitsumi_A1000_Switch; Part Mitsumi standard mechanical Type 2 (KCT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
SW75: KP .; Mitsumi_A1000_Switch; Part Mitsumi standard mechanical Type 2 (KCT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
SW76: KP 8; Mitsumi_A1000_Switch; Part Mitsumi standard mechanical Type 2 (KCT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
SW77: KP 5; Mitsumi_A1000_Switch; Part Mitsumi standard mechanical Type 2 (KCT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
SW78: KP 2; Mitsumi_A1000_Switch; Part Mitsumi standard mechanical Type 2 (KCT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
SW79: KP ENTER; Mitsumi_A1000_Switch; Part Mitsumi standard mechanical Type 2 (KCT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
SW80: KP 7; Mitsumi_A1000_Switch; Part Mitsumi standard mechanical Type 2 (KCT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
SW81: KP 4; Mitsumi_A1000_Switch; Part Mitsumi standard mechanical Type 2 (KCT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
SW82: KP 1; Mitsumi_A1000_Switch; Part Mitsumi standard mechanical Type 2 (KCT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
SW83: KP 0; Mitsumi_A1000_Switch; Part Mitsumi standard mechanical Type 2 (KCT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
SW84: KP -; Mitsumi_A1000_Switch; Part Mitsumi standard mechanical Type 2 (KCT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
SW85: L AMIGA; Mitsumi_A1000_Switch; Part Mitsumi standard mechanical Type 2 (KCT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
SW86: L ALT; Mitsumi_A1000_Switch; Part Mitsumi standard mechanical Type 2 (KCT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
SW87: L SHIFT; Mitsumi_A1000_Switch; Part Mitsumi standard mechanical Type 2 (KCT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
SW88: CTRL; Mitsumi_A1000_Switch; Part Mitsumi standard mechanical Type 2 (KCT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
SW89: R AMIGA; Mitsumi_A1000_Switch; Part Mitsumi standard mechanical Type 2 (KCT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
SW90: R ALT; Mitsumi_A1000_Switch; Part Mitsumi standard mechanical Type 2 (KCT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
SW91: R SHIFT; Mitsumi_A1000_Switch; Part Mitsumi standard mechanical Type 2 (KCT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
SW92: L SHIFT ISO; Mitsumi_A1000_Switch; Part Mitsumi standard mechanical Type 2 (KCT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; not fitted
U1: 6500/1; DIP-40_W15.24mm; Part Commodore 6500/1 keyboard controller, s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
U2: NE556; DIP-14_W7.62mm; Part NE556N dual timer, DIP-14
Y1: 3.000MHz; Crystal_HC49-U_Horizontal; Part 3.000 MHz crystal, HC-49/U

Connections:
+5V: C7.1, C8.1, D1.1 (K), D2.2 (A), FB1.1, R2.1, R3.1, U1.1 (VRR), U1.30 (VCC), U1.40 (~NMI), U2.4 (~RST), U2.10 (~RST), U2.14 (VCC)
/CAPS_LED: Q1.B, U1.22 (PB7)
/KCLK: FB2.1, U1.38 (PA0)
/KCLK_EXT: C2.1, FB2.2, J1.3
/KDAT: FB3.1, U1.37 (PA1)
/KDAT_EXT: C3.1, FB3.2, J1.4
/PA2: SW1.2, SW2.2, SW3.2, SW4.2, SW5.2, SW6.2, SW7.2, SW8.2, SW9.2, SW10.2, SW11.2, SW12.2, U1.36 (PA2)
/PA3: SW13.2, SW14.2, SW15.2, SW16.2, SW17.2, SW18.2, SW19.2, SW20.2, SW21.2, SW22.2, SW23.2, SW24.2, SW25.2, SW26.2, SW27.2, U1.35 (PA3)
/PA4: SW28.2, SW29.2, SW30.2, SW31.2, SW32.2, SW33.2, SW34.2, SW35.2, SW36.2, SW37.2, SW38.2, SW39.2, SW40.2, SW41.2, SW42.2, U1.34 (PA4)
/PA5: SW43.2, SW44.2, SW45.2, SW46.2, SW47.2, SW48.2, SW49.2, SW50.2, SW51.2, SW52.2, SW53.2, SW54.2, SW55.2, SW56.2, SW57.2, U1.33 (PA5)
/PA6: SW58.2, SW59.2, SW60.2, SW61.2, SW62.2, SW63.2, SW64.2, SW65.2, SW66.2, SW67.2, SW68.2, SW69.2, SW70.2, SW71.2, U1.32 (PA6)
/PA7: SW72.2, SW73.2, SW74.2, SW75.2, SW76.2, SW77.2, SW78.2, SW79.2, SW80.2, SW81.2, SW82.2, SW83.2, SW84.2, U1.31 (PA7)
/PB0: SW91.1, U1.29 (PB0)
/PB1: SW90.1, U1.28 (PB1)
/PB2: SW89.1, U1.27 (PB2)
/PB3: SW88.1, U1.26 (PB3)
/PB4: SW87.1, SW92.1, U1.25 (PB4)
/PB5: SW86.1, U1.24 (PB5)
/PB6: SW85.1, U1.23 (PB6)
/PC0: SW12.1, SW27.1, SW42.1, SW57.1, SW71.1, SW84.1, U1.20 (PC0)
/PC1: SW11.1, SW26.1, SW41.1, SW56.1, SW70.1, SW83.1, U1.19 (PC1)
/PC2: SW10.1, SW25.1, SW40.1, SW55.1, SW69.1, SW82.1, U1.18 (PC2)
/PC3: SW9.1, SW24.1, SW39.1, SW54.1, SW81.1, U1.17 (PC3)
/PC4: SW8.1, SW23.1, SW38.1, SW53.1, SW68.1, SW80.1, U1.16 (PC4)
/PC5: SW22.1, SW37.1, SW52.1, SW67.1, SW79.1, U1.15 (PC5)
/PC6: SW7.1, SW21.1, SW36.1, SW51.1, SW66.1, SW78.1, U1.14 (PC6)
/PC7: SW20.1, SW35.1, SW50.1, SW65.1, SW77.1, U1.13 (PC7)
/PD0: SW6.1, SW19.1, SW34.1, SW49.1, SW64.1, SW76.1, U1.9 (PD0)
/PD1: SW5.1, SW18.1, SW33.1, SW48.1, SW63.1, SW75.1, U1.8 (PD1)
/PD2: SW4.1, SW17.1, SW32.1, SW47.1, SW62.1, SW74.1, U1.7 (PD2)
/PD3: SW3.1, SW16.1, SW31.1, SW46.1, SW61.1, SW73.1, U1.6 (PD3)
/PD4: SW2.1, SW15.1, SW30.1, SW45.1, SW60.1, SW72.1, U1.5 (PD4)
/PD5: SW14.1, SW29.1, SW44.1, SW59.1, U1.4 (PD5)
/PD6: SW1.1, SW13.1, SW28.1, SW43.1, SW58.1, U1.3 (PD6)
/RST_CV: C6.1, U2.3 (CONT)
/RST_OUT1: U2.5 (OUT), U2.8 (TRIG), U2.12 (THRES)
/RST_TIMING: C5.1, R3.2, U2.1 (DISCH), U2.2 (THRES)
/RST_TRIG: C4.1, D1.2 (A), R2.2, U2.6 (TRIG)
/VCC_EXT: C1.1, FB1.2, J1.2
/XTLI: U1.10 (XTLI), Y1.1
/XTLO: C9.1, U1.11 (XTLO), Y1.2
/~RESET: U1.39 (~RES), U2.9 (OUT)
GND: C1.2, C2.2, C3.2, C4.2, C5.2, C6.2, C7.2, C8.2, C9.2, H1.1, H2.1, H3.1, H4.1, H5.1, H6.1, H7.1, H8.1, H9.1, J1.1, Q1.E, SW85.2, SW86.2, SW87.2, SW88.2, SW89.2, SW90.2, SW91.2, SW92.2, U1.12 (VSS), U2.7 (GND)
unnamed: D2.1 (K), R1.1
unnamed: Q1.C, R1.2

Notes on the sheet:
Key matrix: rows PA2-PA7, columns PD6-PD0 / PC7-PC0. No diodes in the original design.
Recreated from Commodore drawing 327063 rev B (keyboard assy, Amiga 1000). The original single-sided PCB used wire links J1-J11; these only carried traces over each other and are omitted here, except where noted below. Original J8 / J9 select the extra matrix positions used on international layouts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
Modifier keys (port B, active low)
3.000 MHz: not marked on the drawing, read from the crystal on an assembled board.
Power-on reset (556). Timer A: delay after power-up; timer B inverts it to drive /RES of the 6500/1.
Plate screw holes: plated, tied to GND to ground the steel key plate

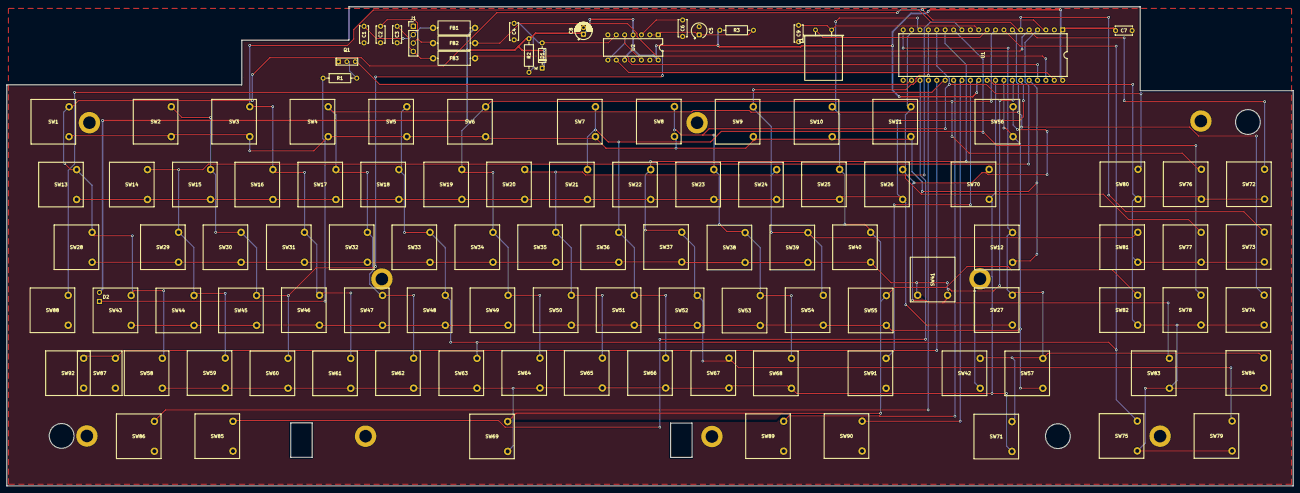
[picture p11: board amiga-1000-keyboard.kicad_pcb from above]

Board: 2 copper layers, 389.2 x 145.0 mm, 126 parts (0 on the bottom side), 45 nets.

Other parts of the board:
H10, H11, H12: Case 7.5mm; MountingHole_7.5mm_CaseClearance

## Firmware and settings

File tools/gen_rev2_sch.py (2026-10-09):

"""Generate the rev 2 schematic (ATmega32U4, SMD, Amiga and USB both live).

    python3 tools/gen_rev2_sch.py      (in the kicad container: it reads the stock symbol libraries)

The switches keep rev 1's references and key names, read from the rev 1 schematic, and rev 1's
positions decide the matrix: each physical row's first 12 keys (left to right) take electrical
rows 0-5, and what is left over fills rows 6 and 7.  Every key has its own diode.

Connections are drawn as a short wire stub and a net label on every pin, so the sheet reads as a
netlist.  UUIDs are derived from names, so regenerating gives the same file.
"""

import os
import re
import sys
import uuid

sys.path.insert(0, os.path.dirname(__file__))
from kisexp import Sym, parse, dump, find, find_all  # noqa: E402

REPO = os.path.dirname(os.path.dirname(os.path.abspath(__file__)))
STOCK = '/usr/share/kicad/symbols'
LOCAL_LIB = os.path.join(REPO, 'pcb/lib_sch/amiga1000.kicad_sym')
REV1_SCH = os.path.join(REPO, 'pcb/amiga-1000-keyboard.kicad_sch')
REV1_PCB = os.path.join(REPO, 'pcb/amiga-1000-keyboard.kicad_pcb')
PROJECT = 'amiga-1000-keyboard-rev2'
OUT = os.path.join(REPO, f'pcb/rev_2/{PROJECT}.kicad_sch')

NS = uuid.UUID('6f1d8a52-3c1e-4c55-9a59-a1000c0de002')
ROOT_UUID = str(uuid.uuid5(NS, 'root'))


def uid(*parts):
    return str(uuid.uuid5(NS, '/'.join(map(str, parts))))


# ------------------------------------------------------------------ pin map

ROWS = ['PF0', 'PF1', 'PF4', 'PF5', 'PF6', 'PF7', 'PC6', 'PD7']       # driven low one at a time
COLS = ['PB0', 'PB1', 'PB2', 'PB3', 'PB4', 'PB5', 'PB6',              # inputs with pull-ups
        'PD0', 'PD1', 'PD4', 'PD5', 'PD6']
MCU_NETS = {
    'PD2': 'KCLK',            # INT2 / RXD1: Henryk's debug UART also lives on clock and data
    'PD3': 'KDAT',            # INT3 / TXD1
    'PB7': 'CAPS_LED',        # OC1C, can dim the LED
    'PE6': 'AMIGA_PWR',       # TPS2116 ST: high while the Amiga's 5 V is the supply in use
    '~{HWB}/PE2': 'HWB',      # held low at reset -> USB bootloader
    'PC7': 'SPARE',           # brought out to a test pad
    '~{RESET}': 'RESET',
    'XTAL1': 'XTAL1', 'XTAL2': 'XTAL2',
    'D+': 'USB_DP_MCU', 'D-': 'USB_DN_MCU',
    'VBUS': 'VBUS', 'UCAP': 'UCAP', 'AREF': 'AREF',
    'VCC': '+5V', 'AVCC': '+5V', 'UVCC': '+5V',
    'GND': 'GND', 'UGND': 'GND',
}
for i, p in enumerate(ROWS):
    MCU_NETS[p] = f'ROW{i}'
for i, p in enumerate(COLS):
    MCU_NETS[p] = f'COL{i}'


# ------------------------------------------------------------------ libraries

_libs = {}


def lib_symbol(lib_id):
    """The library symbol for lib_id, flattened (no `extends`), renamed to the full lib_id."""
    lib, name = lib_id.split(':')
    if lib not in _libs:
        path = LOCAL_LIB if lib == 'amiga1000' else f'{STOCK}/{lib}.kicad_sym'
        _libs[lib] = {s[1]: s for s in find_all(parse(open(path).read()), 'symbol')}
    syms = _libs[lib]
    sym = syms[name]
    ext = find(sym, 'extends')
    if ext:
        parent = lib_symbol(f'{lib}:{ext[1]}')
        own = {p[1]: p for p in find_all(sym, 'property')}
        body = []
        for x in parent[2:]:
            if isinstance(x, list) and x[0] == 'property' and x[1] in own:
                body.append(own.pop(x[1]))
            elif isinstance(x, list) and x[0] == 'symbol':
                body.append([x[0], x[1].replace(ext[1], name, 1)] + x[2:])
            else:
                body.append(x)
        body += list(own.values())
        sym = [Sym('symbol'), name] + body
    out = [sym[0], lib_id] + sym[2:]
    return out


def pins_of(sym):
    """[(number, name, x, y, angle)] in library coordinates (y up)."""
    out = []

    def walk(n):
        for x in n:
            if isinstance(x, list) and x:
                if x[0] == 'pin':
                    at = find(x, 'at')
                    out.append((str(find(x, 'number')[1]), str(find(x, 'name')[1]), at[1], at[2], at[3]))
                elif x[0] == 'symbol':
                    walk(x)
    walk(sym)
    return out


# ------------------------------------------------------------------ sheet items

items = []          # placed symbols, wires, labels, no-connects
used_libs = {}
_pwr_count = [0]


def g(v):
    """Snap to the 1.27 mm grid KiCad connects on."""
    return round(round(v / 1.27) * 1.27, 4)


def prop(name, value, x, y, hide=False, justify=None, angle=0):
    p = [Sym('property'), name, value, [Sym('at'), x, y, angle]]
    if hide:
        p.append([Sym('hide'), Sym('yes')])
    eff = [Sym('effects'), [Sym('font'), [Sym('size'), 1.27, 1.27]]]
    if justify:
        eff.append([Sym('justify')] + [Sym(j) for j in justify.split()])
    p.append(eff)
    return p


def wire(x1, y1, x2, y2):
    items.append([Sym('wire'), [Sym('pts'), [Sym('xy'), x1, y1], [Sym('xy'), x2, y2]],
                  [Sym('stroke'), [Sym('width'), 0], [Sym('type'), Sym('default')]],
                  [Sym('uuid'), uid('wire', x1, y1, x2, y2)]])


def label(net, x, y, outward):
    angle, just = {(-1, 0): (180, 'right bottom'), (1, 0): (0, 'left bottom'),
                   (0, -1): (90, 'left bottom'), (0, 1): (270, 'right bottom')}[outward]
    items.append([Sym('label'), net, [Sym('at'), x, y, angle],
                  [Sym('effects'), [Sym('font'), [Sym('size'), 1.27, 1.27]], [Sym('justify')] + [Sym(j) for j in just.split()]],
                  [Sym('uuid'), uid('label', net, x, y)]])


def no_connect(x, y):
    items.append([Sym('no_connect'), [Sym('at'), x, y], [Sym('uuid'), uid('nc', x, y)]])
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

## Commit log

2026-10-06 recreate the original a1000 keyboard schematic in kicad.
    [amiga-1000-keyboard.kicad_sch]
2026-10-06 ignore kicad local history and borrowed reference photos.
2026-10-06 record board measurements from photos, scans and calipers.
    [switch-positions.csv]
2026-10-06 assign footprints, set the 3mhz crystal and add the iso shift switch.
    [amiga-1000-keyboard.kicad_sch]
2026-10-06 add board outline, mounting holes and measured switch layout.
    [amiga-1000-keyboard.kicad_pcb]
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2026-10-06 place the controller tab parts and tidy reference labels.
    [amiga-1000-keyboard.kicad_pcb]
2026-10-06 record confirmed cable wiring, led polarity and switch checks.
2026-10-06 mark the unfitted cable filter caps c1-c3 do not populate.
    [amiga-1000-keyboard.kicad_sch]
2026-10-06 put the caps lock led anode on the upper lead.
2026-10-06 place the tab parts where the reproduction board has them.
    [amiga-1000-keyboard.kicad_pcb]
2026-10-06 document the white/green wire swap for a 6570 instead of jumpers.
2026-10-06 render the board in ci and show it in the readme.
2026-10-07 use grounded plate holes and a wide e-c-b footprint for the 2sc2021.
2026-10-07 add part fields and a bom generated from the schematic.
    [amiga-1000-keyboard.kicad_sch, bom.csv]
2026-10-07 route the board with a ground pour on both layers.
    [amiga-1000-keyboard.kicad_pcb]
2026-10-07 turn the return switch round and fit sw55 as the dummy support housing.
    [amiga-1000-keyboard.kicad_pcb, amiga-1000-keyboard.kicad_sch, bom.csv]
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2026-10-07 add make targets for drc, bom, gerbers and 1:1 print sheets.
2026-10-07 publish gerbers, bom and print sheets on a version tag.
2026-10-07 generate an fr4 switch plate from the pcb.
2026-10-07 render the plate alongside the board in the readme.
2026-10-07 draw the plate as a flat svg so its render is sharp.
2026-10-07 add version, source board number and repo url to the back silkscreen.
    [amiga-1000-keyboard.kicad_pcb]
2026-10-07 stamp the release tag into the silkscreen version.
2026-10-08 confirm board length by caliper from the case holes.
2026-10-08 shape a printable case after the original from a scale model.
    [a1000_case.scad]
2026-10-08 note what is left to measure for the case.
2026-10-08 hold the 4p4c handset jack where the original has it.
    [a1000_case.scad]
2026-10-08 lay the crystal flat, as on the original, so it fits under the label recess.
    [a1000_case.scad]
2026-10-08 lay y1 flat on the board, can towards the keys, as on the original.
    [a1000_case.scad, amiga-1000-keyboard.kicad_pcb, amiga-1000-keyboard.kicad_sch]
2026-10-09 add a tps2116 power mux to the shared symbol library.
2026-10-09 generate a rev 2 schematic: atmega32u4, smd, amiga and usb both live.
    [amiga-1000-keyboard-rev2.kicad_sch]
2026-10-09 spread the rev 2 schematic over the page and keep text off the stubs.
    [amiga-1000-keyboard-rev2.kicad_sch]
2026-10-09 take mitsumi or mx switches on rev 2, with a caps lock led for each.
    [amiga-1000-keyboard-rev2.kicad_sch]
2026-10-09 give return a hybrid footprint with a vertical stabiliser, after henryk's us return.
    [amiga-1000-keyboard-rev2.kicad_sch]
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2026-10-09 take cherry mx switches only on rev 2; rev 1 stays the mitsumi board.
    [amiga-1000-keyboard-rev2.kicad_sch]
2026-10-09 generate and route the rev 2 board, placed from rev 1's outline.
    [amiga-1000-keyboard-rev2.kicad_pcb]
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2026-10-09 move the rev 2 controller to the right and swap its buttons for jumper pads.
    [amiga-1000-keyboard-rev2.kicad_pcb, amiga-1000-keyboard-rev2.kicad_sch]
2026-10-09 add lcsc part numbers to rev 2, with 12 pf load caps for its 9 pf crystal.
    [amiga-1000-keyboard-rev2.kicad_pcb, amiga-1000-keyboard-rev2.kicad_sch]
2026-10-09 build rev 2's gerbers, bom and placement for jlcpcb on every push.
2026-10-09 generate us and iso mx plates for rev 2 and build them for jlcpcb too.
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2026-10-09 cut the bosses under the pcb to a 1 mm shoulder so they pass through it.
2026-10-09 raise the lip to the original's 3.8 mm and build it up from the floor so it prints.
2026-10-09 widen the jack opening to the original's 15.5 mm, lined up with the box.
2026-10-09 match the jack box to the original: stop, wire cutout and floor-deep opening.
2026-10-10 size the jack box from the jack itself, and add a jack-corner test print.
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2026-10-10 generate the rev 2 keymap from the matrix the schematic is drawn from.
2026-10-11 use the project's own pid.codes usb id, 1209:a10b, in place of the test id.
2026-10-11 shorten the key well skirts to the original's 8.65 mm so the top clamps down square.
2026-10-12 pin the case's scarf joints with filament dowels so they can't slide while the glue sets.
2026-10-12 snap the long edges of the case together between the screws.
2026-10-12 stop the screw columns level with the skirts, clear of the plate.
2026-10-12 add a test print of both glue joints and a snap.
2026-10-13 print each shell in one piece on beds big enough to take the whole case.
2026-10-21 record that the first rev 2 board flashes and types over usb.
2026-10-22 print a1000-sized mx keycaps in cherry profile for the keys mx sets lack.
2026-10-22 keep sw55 on the us plate for the return cap's dummy switch.
2026-10-22 fit the case to rev 2: usb-c opening, thinner stack, spacers for rev 1 cases.
2026-10-22 record that the first rev 2 boards are programmed and fully tested over usb.

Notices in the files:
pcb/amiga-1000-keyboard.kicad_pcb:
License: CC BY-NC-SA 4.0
